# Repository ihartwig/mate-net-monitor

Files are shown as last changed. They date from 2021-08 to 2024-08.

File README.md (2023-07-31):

# mate-net-monitor
Baseboard PCBA for MATE Net and Magnum Net power system monitoring with a Particle Boron.

## GPIO Pin Usage

| Pin | Function | Usage |
|-----|---|---|
| 0 | SDA | -- (expansion connector)
| 1 | SCL | -- (expansion connector)
| 2 | D2 / SPI_SCK | -- (Mag Net activity indicator low)
| 3 | D3 / SPI_MOSI | -- (Mag Net xcvr enable low unpopulated)
| 4 | D4 / SPI_MISO | -- (Mag Net UART TX?)
| 5 | D5 | -- (Mag Net UART RX?)
| 6 | D6 | IRQ from MAX3100 adpt
| 7 | D7 | --
| 8 | D8 | --
| 9 | D9 / UART1_TX | UART from MAX3100 adpt
| 10  | D10 / UART1_RX  | UART to MAX3100 adpt
| 11  | MI | SPI to MAX3100 adpt
| 12  | MO | SPI to MAX3100 adpt
| 13  | SCK | SPI to MAX3100 adpt
| 14  | A5 / SPI_SS | SPI to MAX3100 adpt
| 15  | A4 | -- (expansion connector)
| 16  | A3 | -- (expansion connector)
| 17  | A2 | -- (expansion connector)
| 18  | A1 | -- (expansion connector)
| 19  | A0 | MATE Net activity indicator high
| 20  | | --

## Hardware

* [pcb](pcb) - main baseboard with connectors and interface circuits for MATE Net and Magnum Net
* [pcb-max3100-uart-adpt](pcb-max3100-uart-adpt) - extra max3100 UART port (capable of 9N1) for MATE Net

The `pcb` dc-dc power supply required some rework to achieve stable operation.

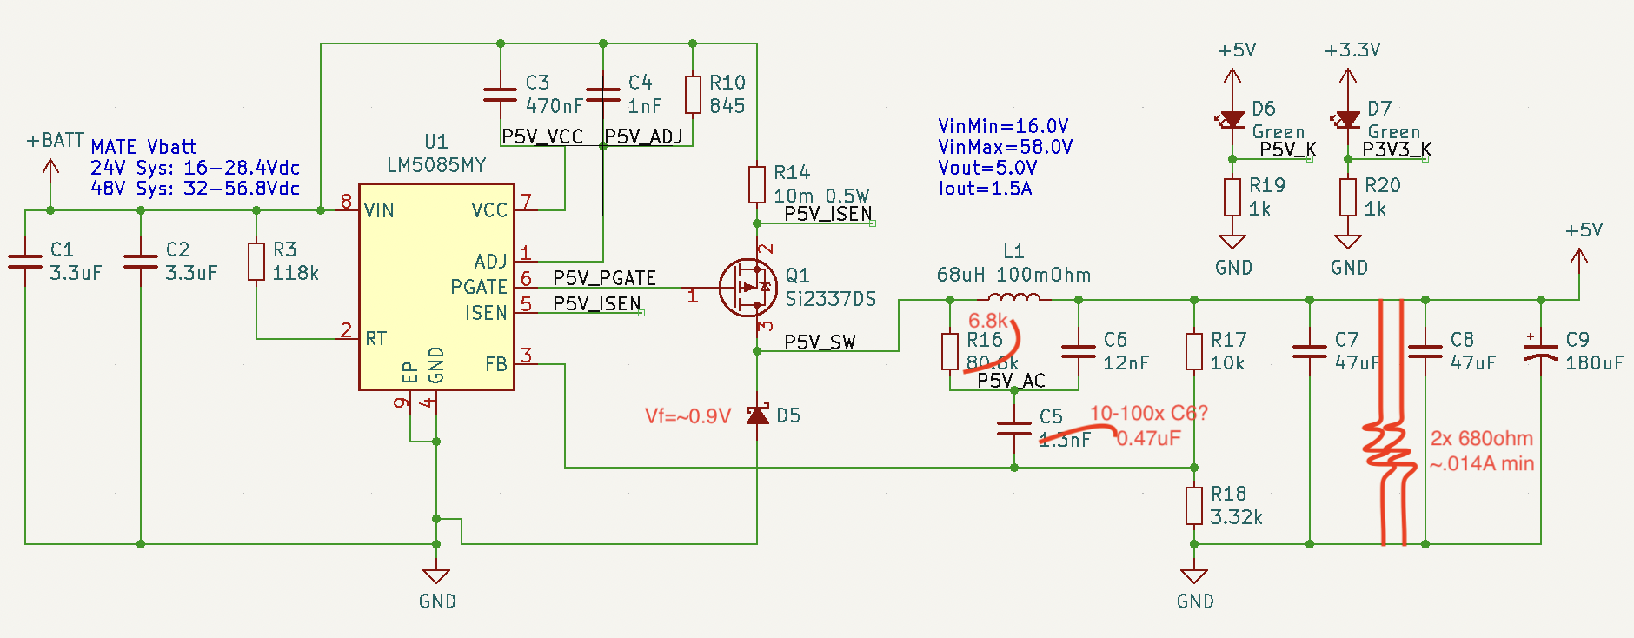
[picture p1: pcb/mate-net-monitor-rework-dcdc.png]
mate-net-monitor-rework-dcdc


Additionally, some modifications during assembly are required compared to the as-designed files here. This primarily addresses pin assignment issues:

* Mag Net is attached to pins that do not have a UART; remap these on the Boron board as the internal UART can be used for this.
* Mate Net needs a 9-bit capable UART; stack the `pcb-max3100-uart-adpt` on the bottom side of the `pcb` mainboard to add this.
  * GND, 3V3, and /IRQ on the far side need to be wired to sources on the mainboard.
  * /SHDN needs to be pulled up (via 10k) to 3V3.

## Firmware

* [fw-mate-net-monitor](fw-mate-net-monitor) - WIP application firmware for reporting MATE inverter stats to particle cloud
* [fw-test](fw-test) - simple hardware test firmware for burn-in testing of interfaces

Inside the `fw-test` folder there is a MAX3100Serial9B library extended from [ewpa's MAX3100Serial](https://github.com/ewpa/MAX3100Serial) with some adaptations to Particle and significant new features:

* addition of software buffers and interrupt handling for continuous stream operation
* irq, sent, read, and overflow counters
* (WIP) 9-bit read and write configuration

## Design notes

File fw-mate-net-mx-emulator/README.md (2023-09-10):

# fw-mate-net-monitor

A Particle project named fw-mate-net-monitor

This project implements the uMATE library on top of Particle Boron with a mate-net-monitor adapter board to act like the status screen on a MATE controller and save this data to a cloud database.

More details on the [MATE-to-MX protocol](https://github.com/jorticus/pymate/blob/master/doc/protocol/Protocol.md) have been documented by jorticus - thank you! The simple implementation here requests the device type and status page from port 0 every 3 minutes. The bus is scanned more frequently (approx. every 1 second) to drive MATE Net LEDs.

#### LED Indicators:

MATE Net Port Green: powered up (+24V) from this port

MATE Net Port Orange: solid for running port scan; blinking when at least one MATE device is found during last scan

Mag Net Green: ports A and B are connected correctly based on the +14V power; power is not drawn from this port

Mag Net Orange: not implemented

Mag Net Red: ports A and B are swapped

#### Limitations:
* always asks for the MX Charger status on port 0 if it is not discovered on another port
* * mate bus scan to discover devices behind Hub is implemented, but not tested with a Hub
* Mag net ports are not implemented - should have no impact since that is a multi-drop bus

#### Topology:

```
Particle Cloud
       |
      LTE
       |               MAX3100 UART &
     Boron --- SPI --- Opto-Isolation --- MATE-net --- MX Charger
                       3.3V       24V
```

#### Library modifications:

* uMate has extra #define OUT statements commented for conflict with Particle libs
* MAX3100Serial9b includes a compatible Stream9b.h to the one used in uMate

## Welcome to your project!

Every new Particle project is composed of 3 important elements that you'll see have been created in your project directory for fw-mate-net-monitor.

#### ```/src``` folder:  
This is the source folder that contains the firmware files for your project. It should *not* be renamed. 
Anything that is in this folder when you compile your project will be sent to our compile service and compiled into a firmware binary for the Particle device that you have targeted.

If your application contains multiple files, they should all be included in the `src` folder. If your firmware depends on Particle libraries, those dependencies are specified in the `project.properties` file referenced below.

#### ```.ino``` file:
This file is the firmware that will run as the primary application on your Particle device. It contains a `setup()` and `loop()` function, and can be written in Wiring or C/C++. For more information about using the Particle firmware API to create firmware for your Particle device, refer to the [Firmware Reference](https://docs.particle.io/reference/firmware/) section of the Particle documentation.

#### ```project.properties``` file:  
This is the file that specifies the name and version number of the libraries that your project depends on. Dependencies are added automatically to your `project.properties` file when you add a library to a project using the `particle library add` command in the CLI or add a library in the Desktop IDE.

## Adding additional files to your project

#### Projects with multiple sources
If you would like add additional files to your application, they should be added to the `/src` folder. All files in the `/src` folder will be sent to the Particle Cloud to produce a compiled binary.

#### Projects with external libraries
If your project includes a library that has not been registered in the Particle libraries system, you should create a new folder named `/lib/<libraryname>/src` under `/<project dir>` and add the `.h`, `.cpp` & `library.properties` files for your library there. Read the [Firmware Libraries guide](https://docs.particle.io/guide/tools-and-features/libraries/) for more details on how to develop libraries. Note that all contents of the `/lib` folder and subfolders will also be sent to the Cloud for compilation.

## Compiling your project

When you're ready to compile your project, make sure you have the correct Particle device target selected and run `particle compile <platform>` in the CLI or click the Compile button in the Desktop IDE. The following files in your project folder will be sent to the compile service:

- Everything in the `/src` folder, including your `.ino` application file
- The `project.properties` file for your project
- Any libraries stored under `lib/<libraryname>/src`

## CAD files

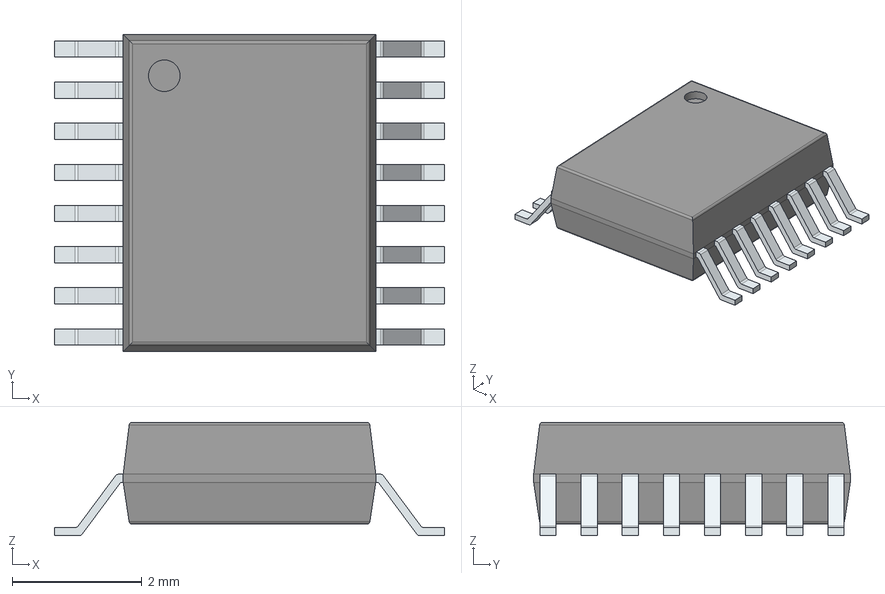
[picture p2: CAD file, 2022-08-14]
pcb-max3100-uart-adpt/max3100-uart-adpt-special-packages3d/MAX3100EEE+.stp
6.02 x 4.89 x 1.75 mm
PinsArrayLR

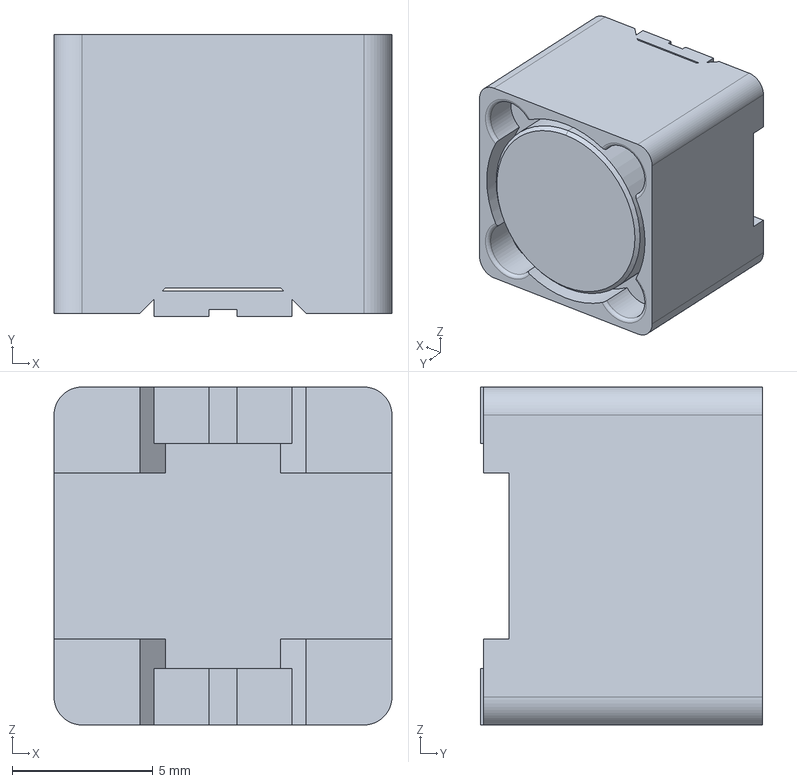
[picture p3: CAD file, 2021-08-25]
pcb/mate-net-monitor-special-packages3d/L_Bourns_SRR1210.stp
12.0 x 10.0 x 12.0 mm

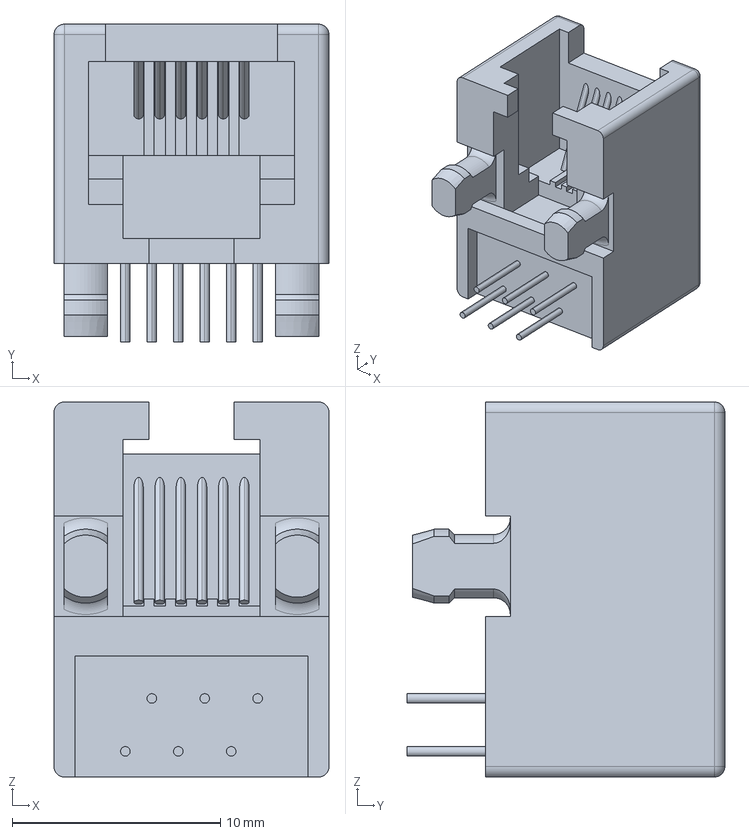
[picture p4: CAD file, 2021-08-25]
pcb/mate-net-monitor-special-packages3d/RJ12_Amphenol_54601.stp
13.2 x 15.2 x 18.0 mm

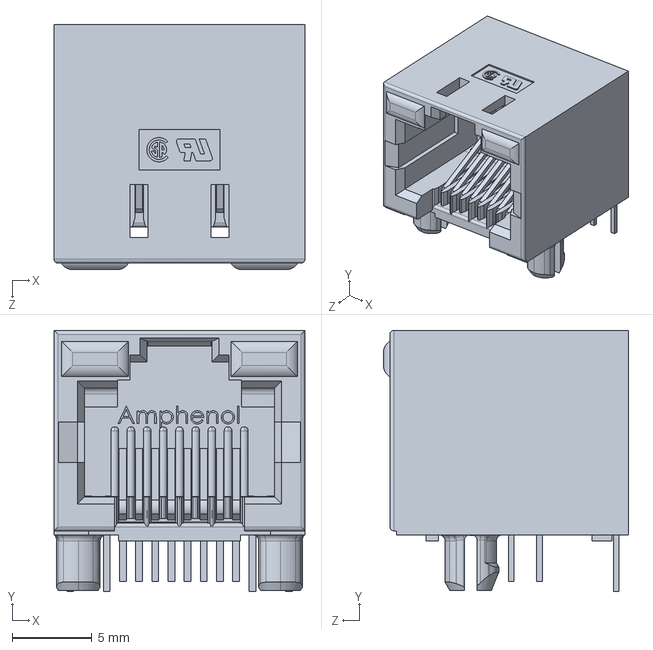
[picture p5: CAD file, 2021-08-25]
pcb/mate-net-monitor-special-packages3d/RJ45_Amphenol_RJHSE508X.step
15.7 x 16.4 x 15.4 mm

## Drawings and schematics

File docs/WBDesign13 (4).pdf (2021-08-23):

## WEBENCH ® Design Report

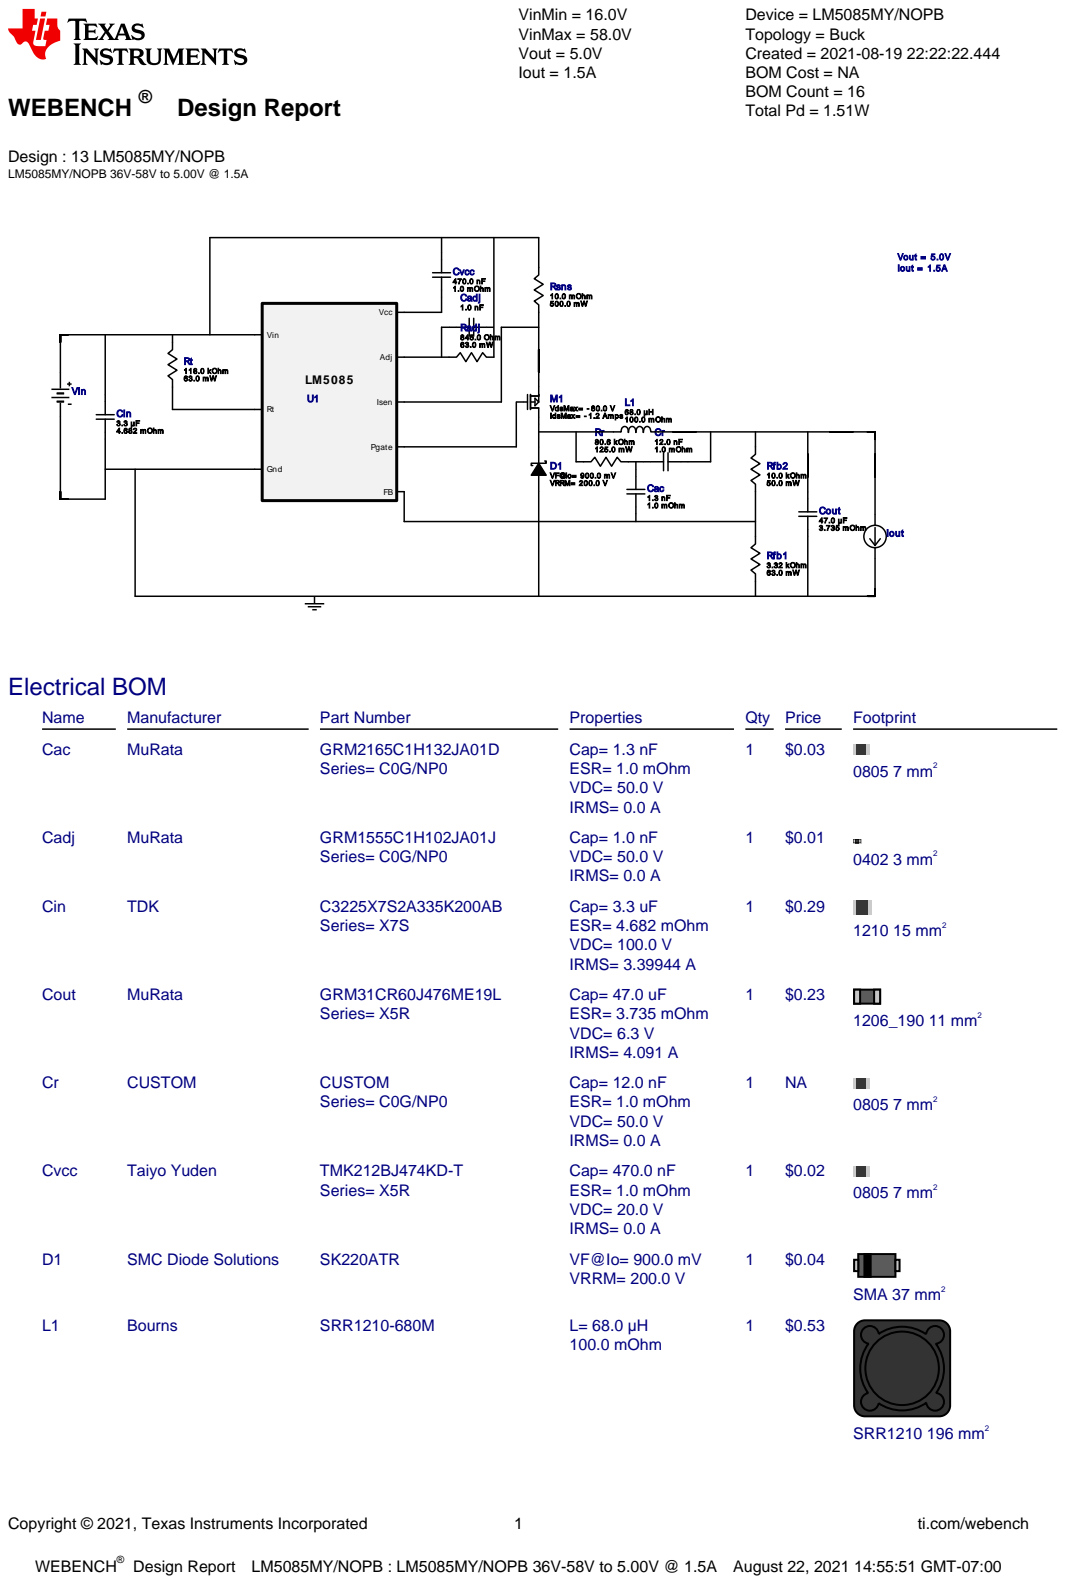
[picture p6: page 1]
Copyright © 2021, Texas Instruments Incorporated; ti.com/webench; WEBENCH®; Design : 13 LM5085MY/NOPB LM5085MY/NOPB 36V-58V to 5.00V @ 1.5A; VinMin = 16.0V VinMax = 58.0V Vout = 5.0V Iout = 1.5A; Cac 1.3 nF 1.0 mOhm; Cadj 1.0 nF; Cin 3.3 µF 4.682 mOhm; Cout 47.0 µF 3.735 mOhm; Cr 12.0 nF 1.0 mOhm; Cvcc 470.0 nF 1.0 mOhm; D1 VF@Io= 900.0 mV VRRM= 200.0 V; L1 68.0 µH 100.0 mOhm; M1 VdsMax= - 80.0 V IdsMax= - 1.2 Amps; Radj 845.0 Ohm 63.0 mW; Rfb1 3.32 kOhm 63.0 mW; Rfb2 10.0 kOhm 50.0 mW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

Device = LM5085MY/NOPB
Topology = Buck
Created = 2021-08-19 22:22:22.444
BOM Cost = NA
BOM Count = 16
Total Pd = 1.51W

Design Report LM5085MY/NOPB : LM5085MY/NOPB 36V-58V to 5.00V @ 1.5A August 22, 2021 14:55:51 GMT-07:00

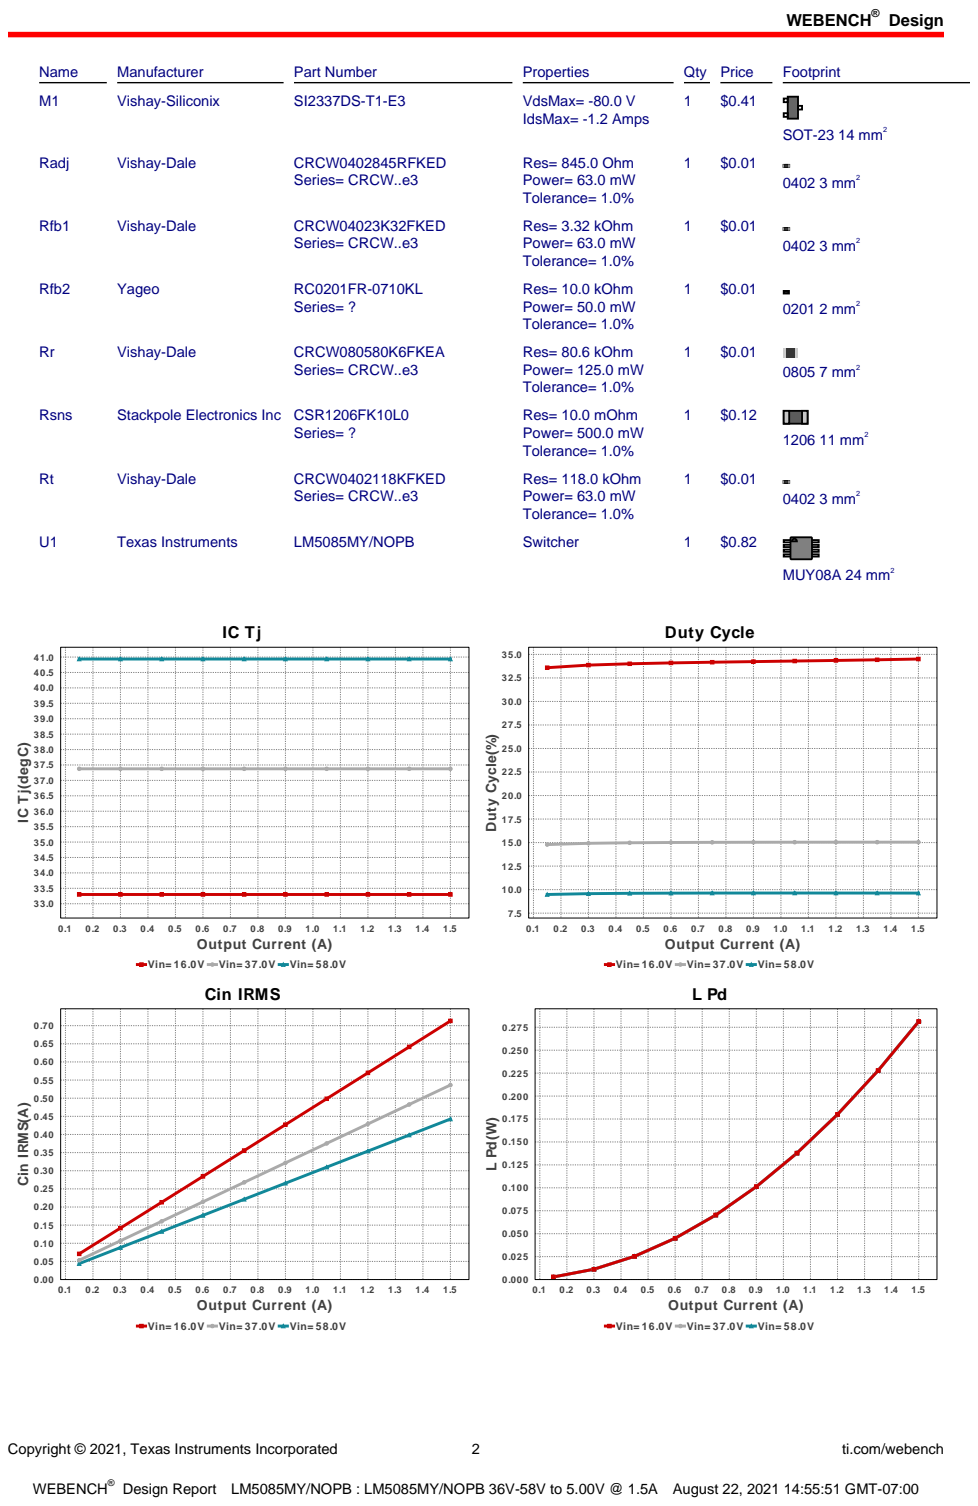
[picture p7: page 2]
Design; Copyright © 2021, Texas Instruments Incorporated; ti.com/webench; Name; Manufacturer; Part Number; Properties; Qty Price; Footprint; Vishay-Siliconix; VdsMax= -80.0 V; IdsMax= -1.2 Amps; SOT-23 14 mm²; Radj; Vishay-Dale; CRCW0402845RFKED; Series= CRCW..e3; Res= 845.0 Ohm Power= 63.0 mW Tolerance= 1.0%; 0402 3 mm²; Rfb1; CRCW04023K32FKED; Res= 3.32 kOhm Power= 63.0 mW Tolerance= 1.0%; Rfb2; Yageo; Series= ?; Res= 10.0 kOhm Power= 50.0 mW Tolerance= 1.0%; 0201 2 mm²; CRCW080580K6FKEA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

IC Tj(degC)

Vin= 16.0V Vin= 37.0V Vin= 58.0V
Cin IRMS

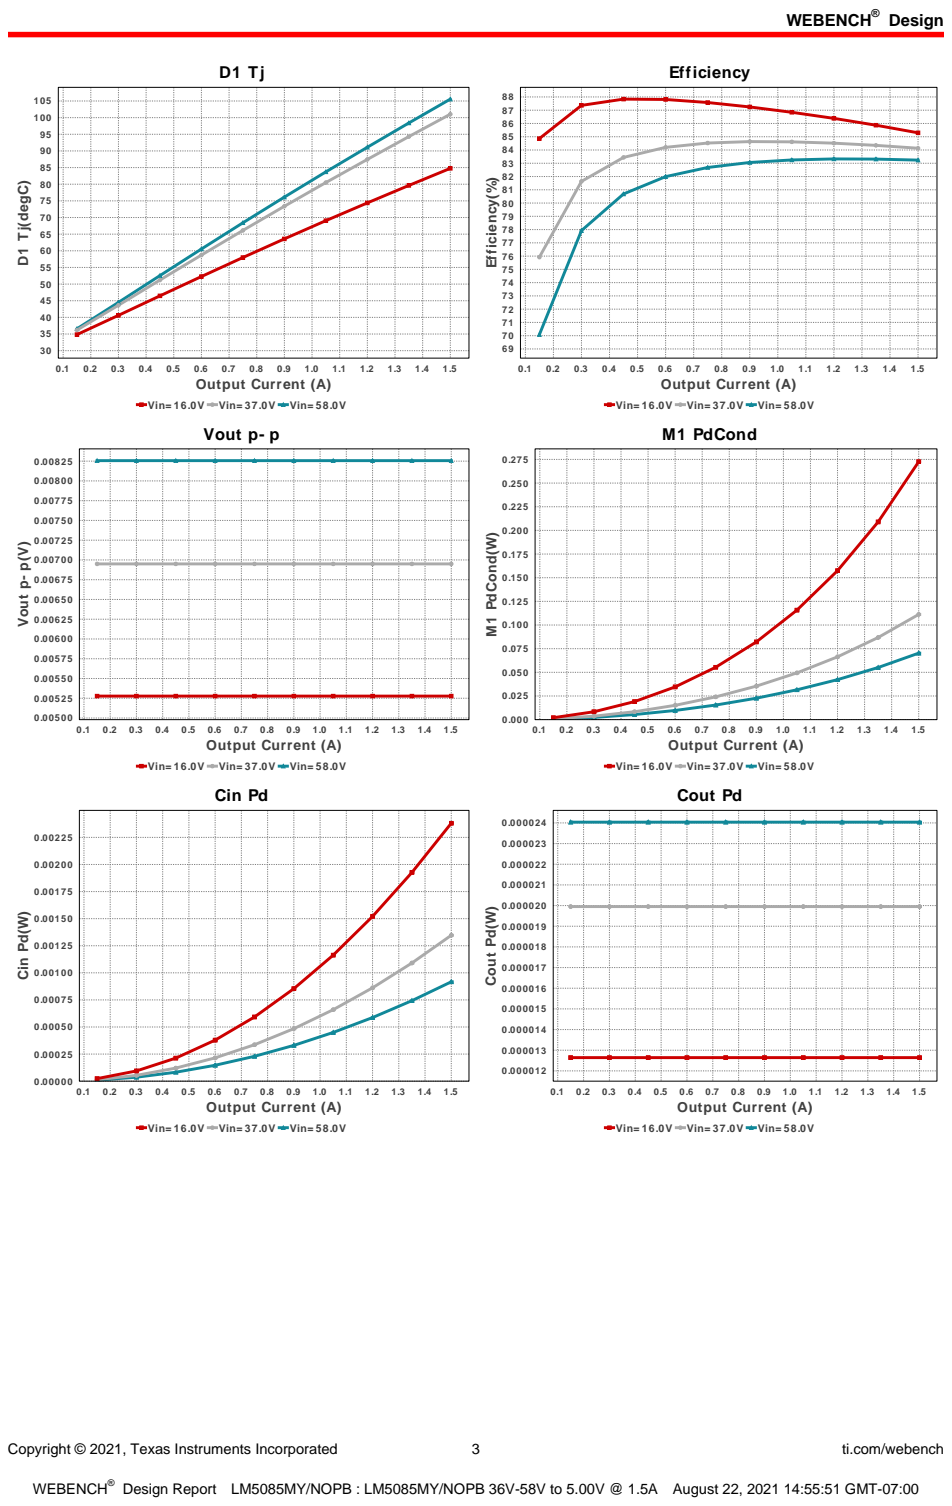
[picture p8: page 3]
Copyright © 2021, Texas Instruments Incorporated; ti.com/webench; 1.5 Output Current (A); D1 Tj(degC); Efficiency; Efficiency(%); 0.1 0.2 0.3 0.4 0.5 0.6 0.7 0.8 0.9 1.0 1.1 1.2 1.3 1.4 1.5 Output Current (A); Vout p- p(V); M1 PdCond(W); Cin Pd; Cin Pd(W); Cout Pd; Cout Pd(W)

Vin= 16.0V Vin= 37.0V Vin= 58.0V
Vout p- p

M1 PdCond

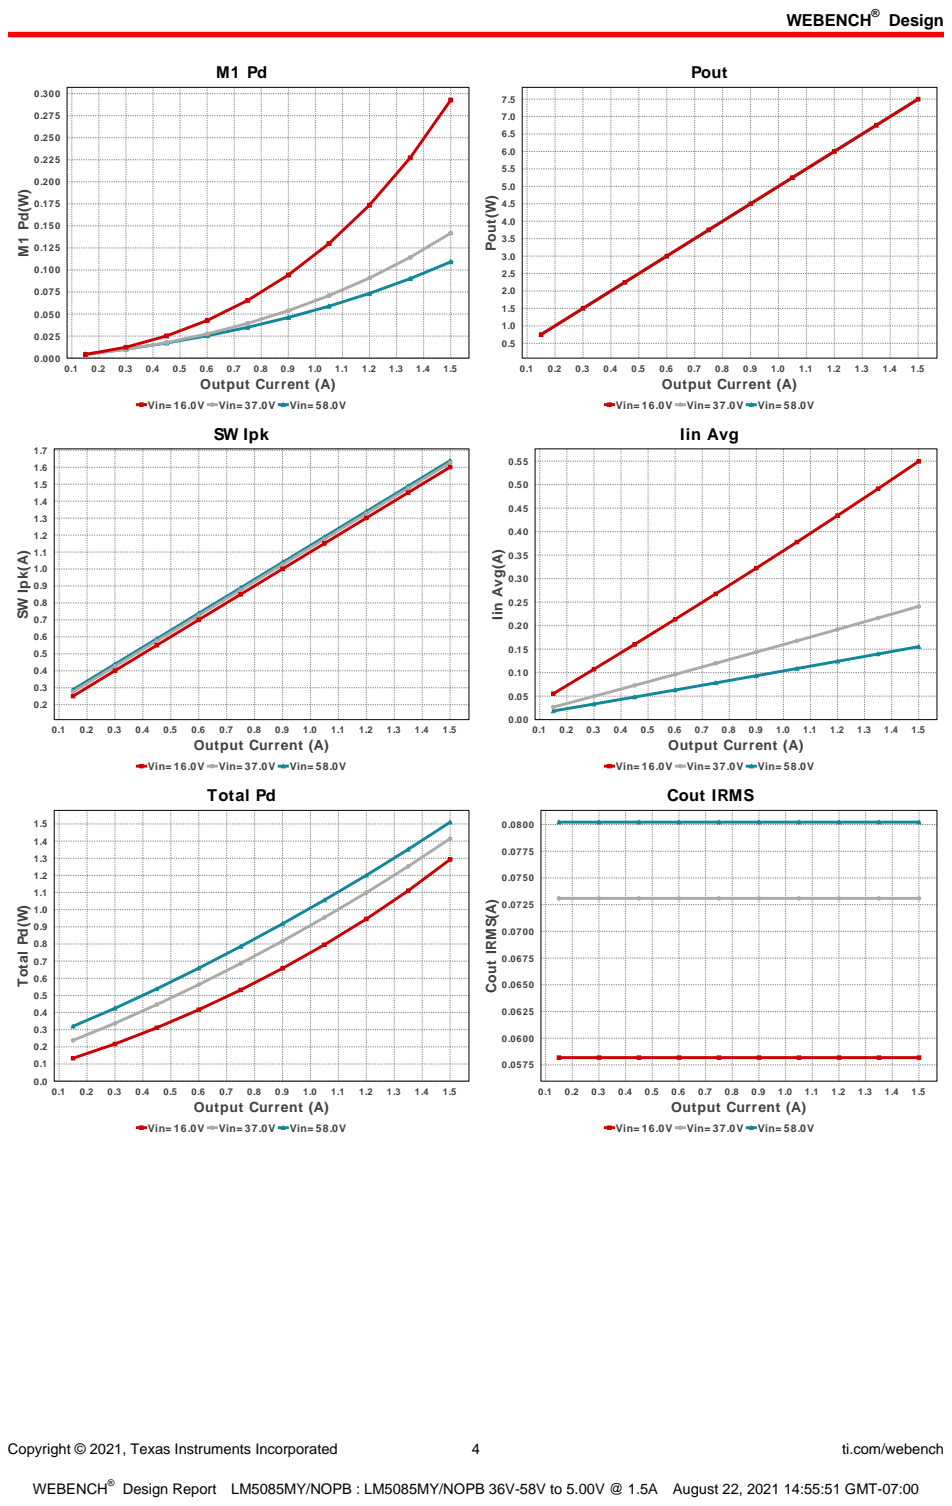
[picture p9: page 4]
Copyright © 2021, Texas Instruments Incorporated; ti.com/webench; 1.5 Output Current (A); Pout; Pout(W); SW Ipk; SW Ipk(A); Iin Avg; Iin Avg(A); Total Pd; Total Pd(W); 0.1 0.2 0.3 0.4 0.5 0.6 0.7 0.8 0.9 1.0 1.1 1.2 1.3 1.4 1.5 Output Current (A); Cout IRMS(A)

Vin= 16.0V Vin= 37.0V Vin= 58.0V

Cout IRMS

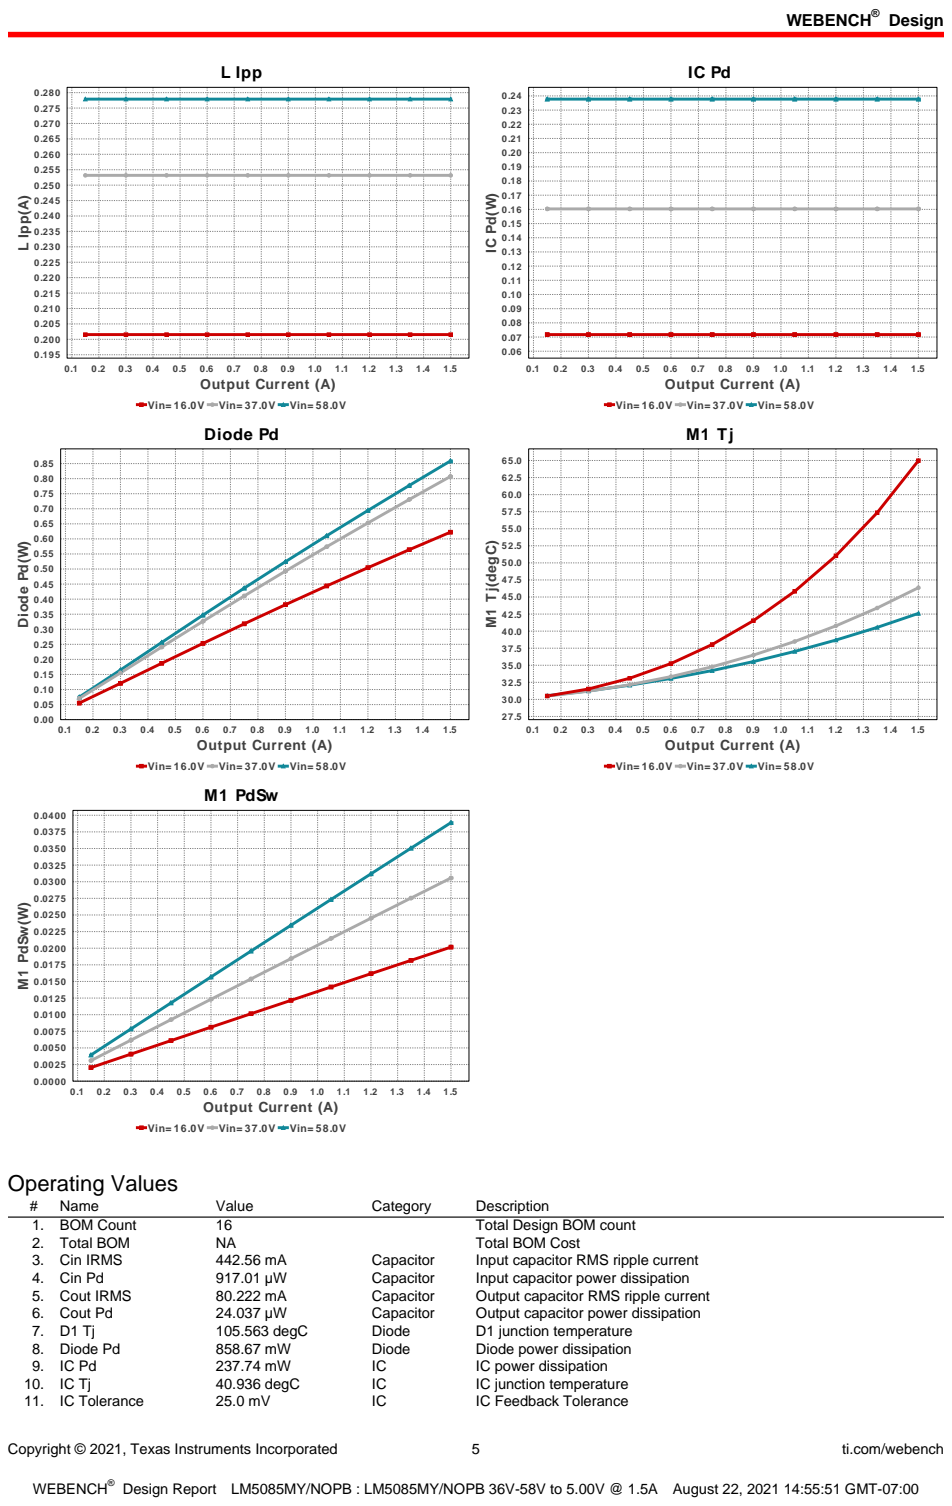
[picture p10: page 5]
Copyright © 2021, Texas Instruments Incorporated; ti.com/webench; L Ipp; 1.5 Output Current (A); L Ipp(A); Diode Pd(W); M1 Tj(degC); 0.1 0.2 0.3 0.4 0.5 0.6 0.7 0.8 0.9 1.0 1.1 1.2 1.3 1.4 1.5 Output Current (A); M1 PdSw(W); Operating Values; Name; Value; Category; Description; 1. BOM Count; Total Design BOM count; 2. Total BOM; Total BOM Cost; 3. Cin IRMS; Capacitor; Input capacitor RMS ripple current; 4. Cin Pd; Input capacitor power dissipation; 5. Cout IRMS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

Vin= 16.0V Vin= 37.0V Vin= 58.0V
Diode Pd

M1 PdSw

Copyright © 2021, Texas Instruments Incorporated | 6 | ti.com/webench
# | Name | Value | Category | Description

12. ICThetaJA | 46.0 degC/W | IC | IC junction-to-ambient thermal resistance
13. Iin Avg | 155.35 mA | IC | Average input current
14. L Ipp | 277.898 mA | Inductor | Peak-to-peak inductor ripple current
15. L Pd | 281.25 mW | Inductor | Inductor power dissipation
16. M1 Pd | 109.18 mW | Mosfet | M1 MOSFET total power dissipation
17. M1 PdCond | 70.287 mW | Mosfet | M1 MOSFET conduction losses
18. M1 PdSw | 38.892 mW | Mosfet | M1 MOSFET switching losses
19. M1 Tj | 42.599 degC | Mosfet | M1 MOSFET junction temperature
20. Cin Pd | 917.01 µW | Power | Input capacitor power dissipation
21. Cout Pd | 24.037 µW | Power | Output capacitor power dissipation
22. Diode Pd | 858.67 mW | Power | Diode power dissipation
23. IC Pd | 237.74 mW | Power | IC power dissipation
24. L Pd | 281.25 mW | Power | Inductor power dissipation
25. M1 Pd | 109.18 mW | Power | M1 MOSFET total power dissipation
26. M1 PdCond | 70.287 mW | Power | M1 MOSFET conduction losses
27. M1 PdSw | 38.892 mW | Power | M1 MOSFET switching losses
28. Total Pd | 1.51 W | Power | Total Power Dissipation
29. Duty Cycle | 9.633 % | System
| | | Information | Duty cycle
30. Efficiency | 83.238 % | System
| | | Information | Steady state efficiency
31. FootPrint | 349.0 mm² | System
| | | Information | Total Foot Print Area of BOM components
32. Frequency | 212.046 kHz | System
| | | Information | Switching frequency
33. Iout | 1.5 A | System
| | | Information | Iout operating point
34. Mode | CCM | System
| | | Information | Conduction Mode
35. Pout | 7.5 W | System
| | | Information | Total output power
36. SW Ipk | 1.639 A | System
| | | Information | Peak switch current
37. Vin | 58.0 V | System
| | | Information | Vin operating point
38. Vout | 5.0 V | System
| | | Information | Operational Output Voltage
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

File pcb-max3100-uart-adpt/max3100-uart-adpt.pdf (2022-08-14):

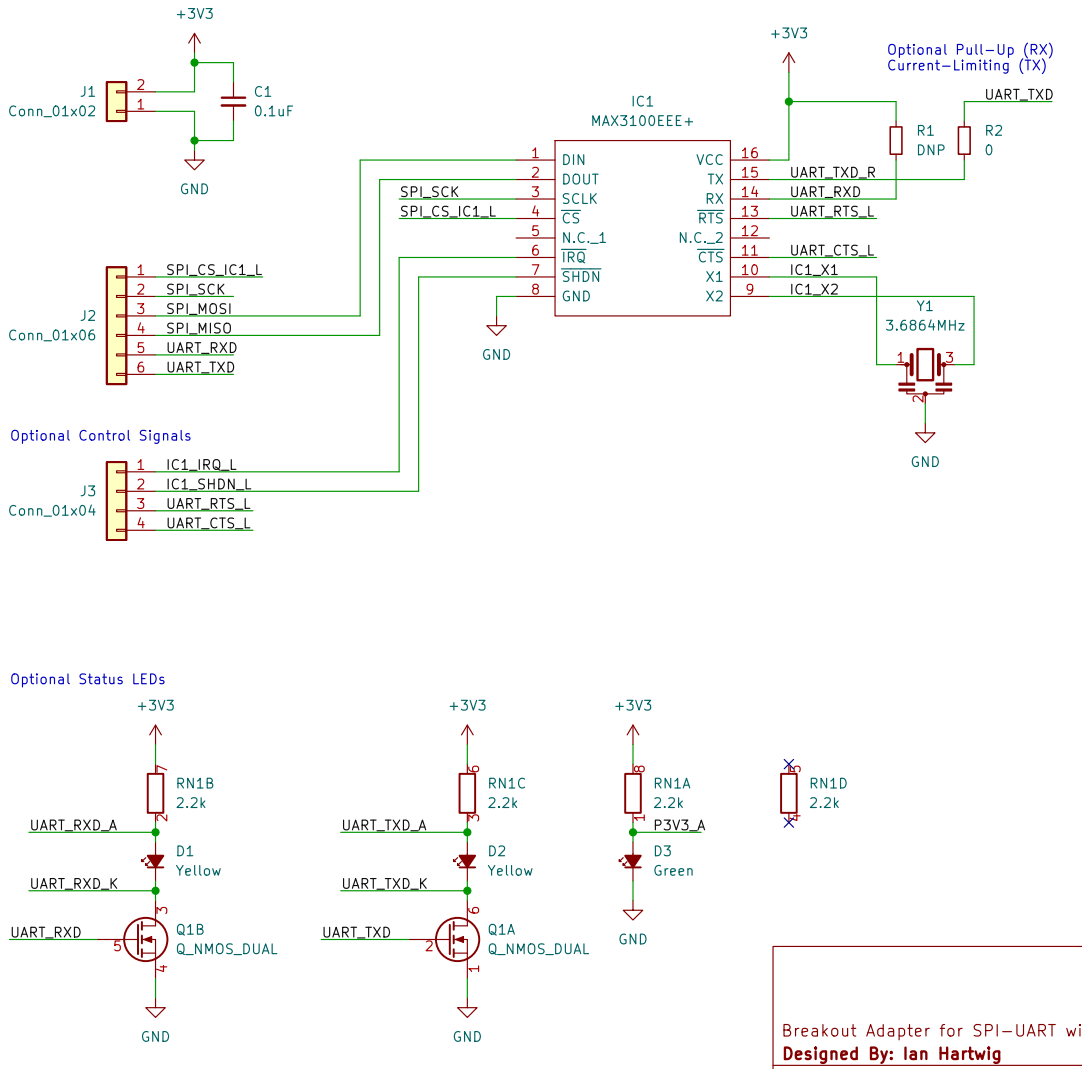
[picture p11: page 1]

Optional Pull-Up (RX)
Current-Limiting (TX)

3.6864MHz GND GND
Breakout Adapter for SPI-UART with pin layout matching mate-net-monitor baseboard GND

File: max3100-uart-adpt.kicad_sch Sheet: / Designed By: Ian Hartwig

Id: 1/1 Title: MAX3100 UART Adapter

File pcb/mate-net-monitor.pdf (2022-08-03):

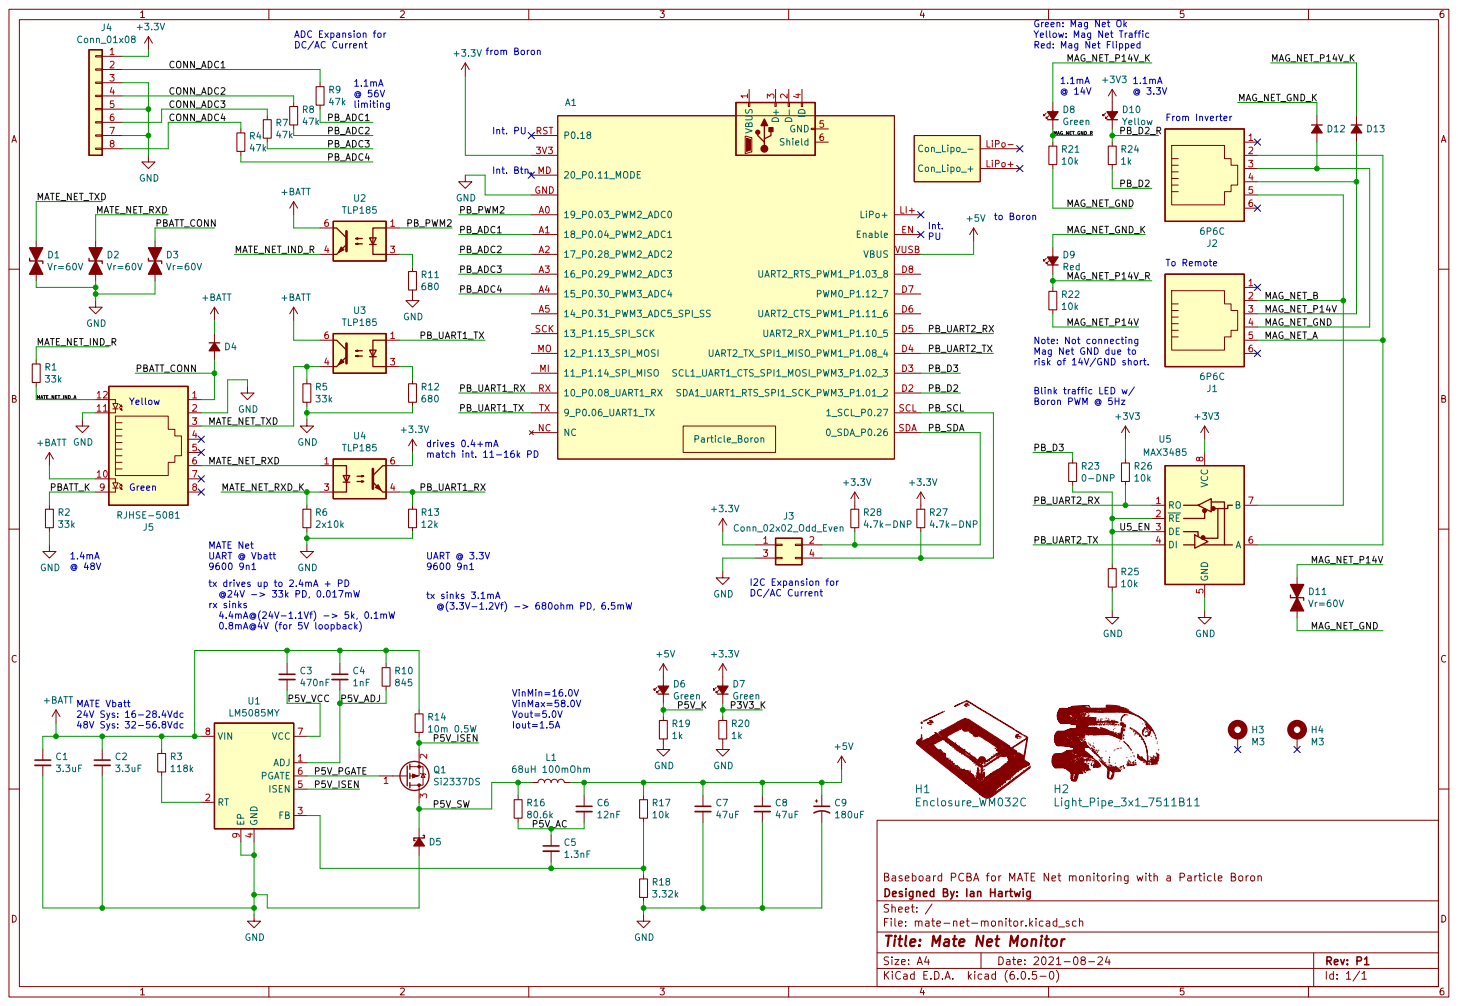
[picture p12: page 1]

1.1mA @ 14V Green: Mag Net Ok
Yellow: Mag Net Traffic
Red: Mag Net Flipped
From Inverter To Remote

risk of 14V/GND short. 1.4mA @ 48V MATE Vbatt 24V Sys: 16-28.4Vdc

Mag Net GND due to

drives 0.4+mA match int. 11-16k PD

tx drives up to 2.4mA + PD
rx sinks
0.8mA@4V (for 5V loopback)

I2C Expansion for DC/AC Current

Baseboard PCBA for MATE Net monitoring with a Particle Boron
File: mate-net-monitor.kicad_sch Sheet: / Designed By: Ian Hartwig

Id: 1/1 Title: Mate Net Monitor

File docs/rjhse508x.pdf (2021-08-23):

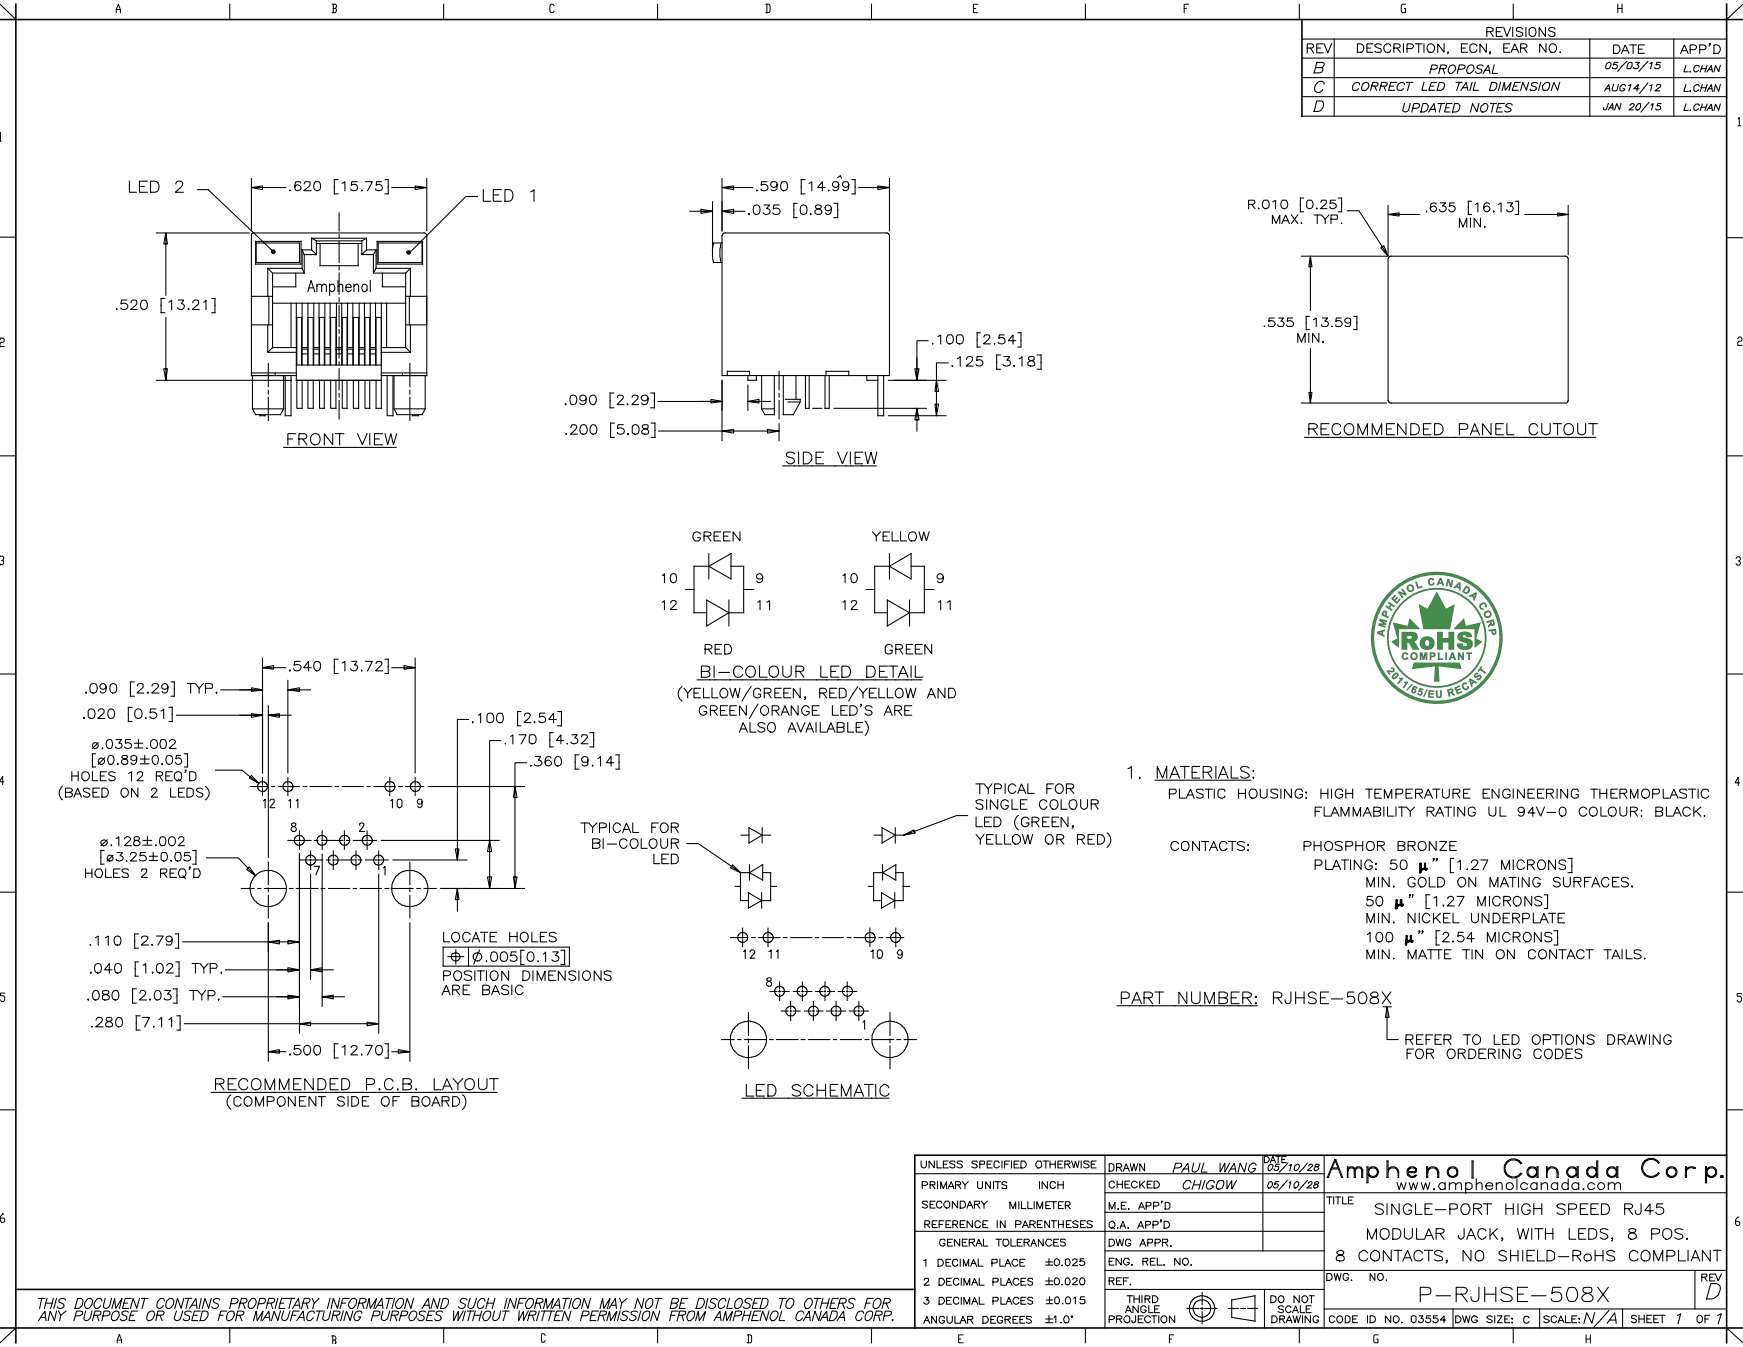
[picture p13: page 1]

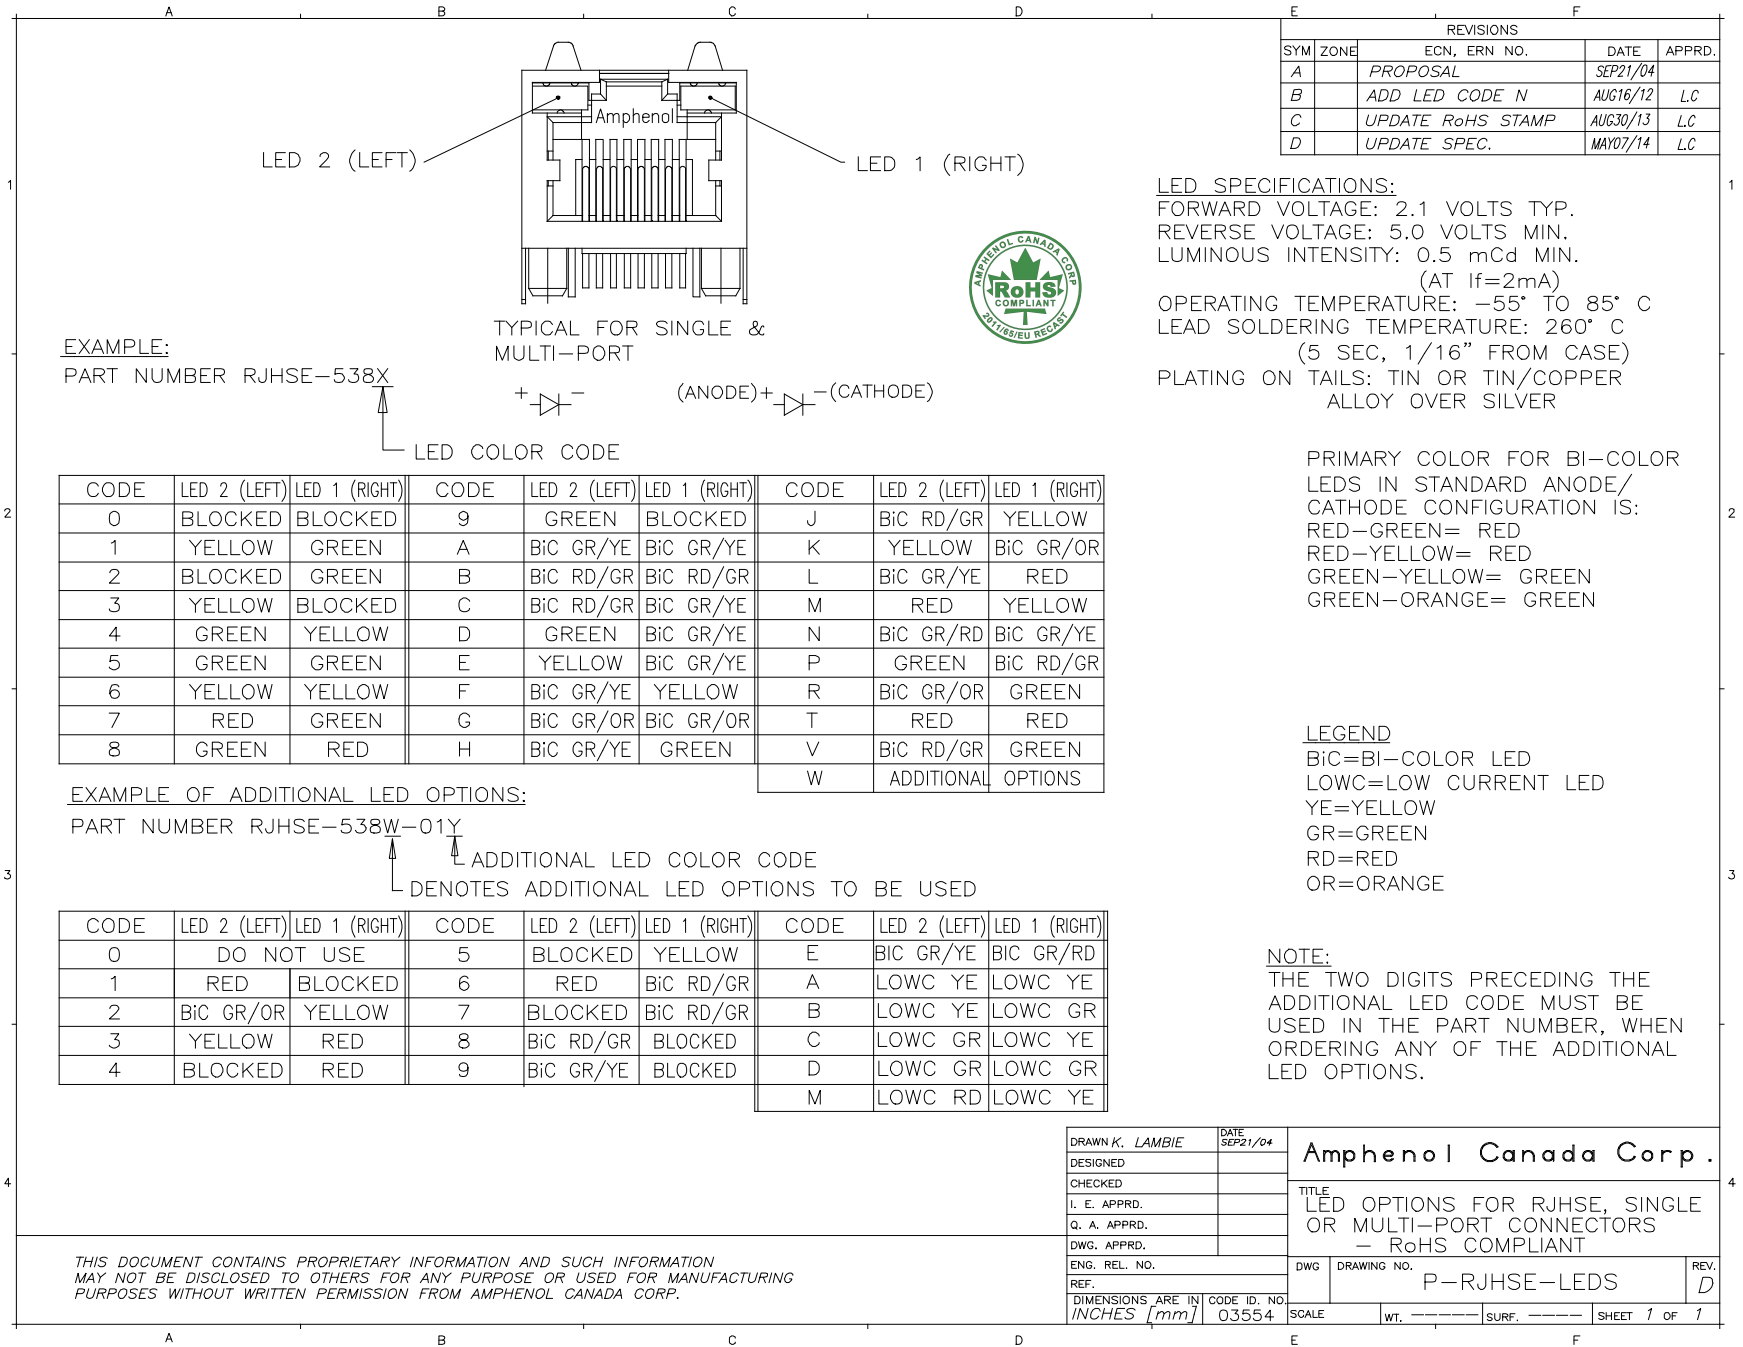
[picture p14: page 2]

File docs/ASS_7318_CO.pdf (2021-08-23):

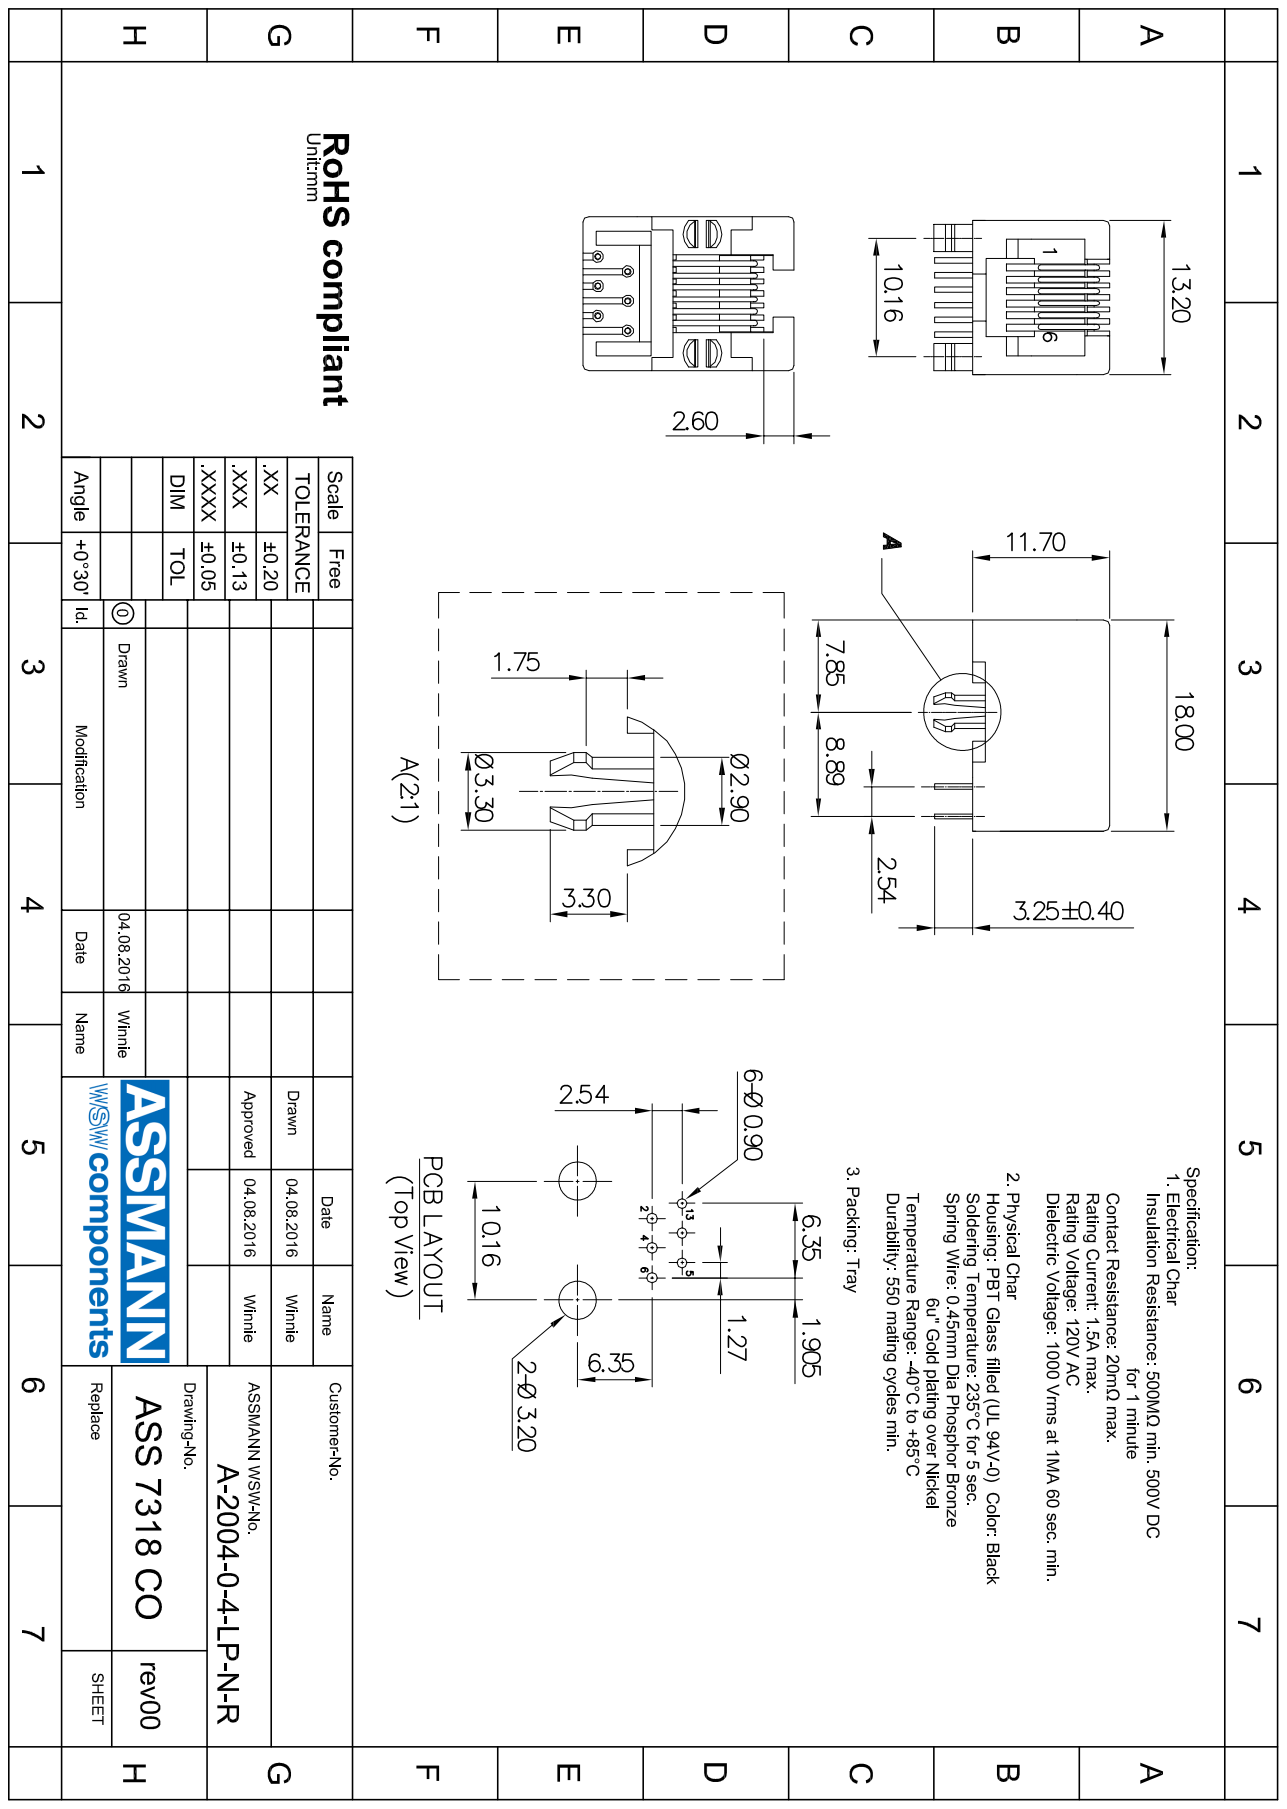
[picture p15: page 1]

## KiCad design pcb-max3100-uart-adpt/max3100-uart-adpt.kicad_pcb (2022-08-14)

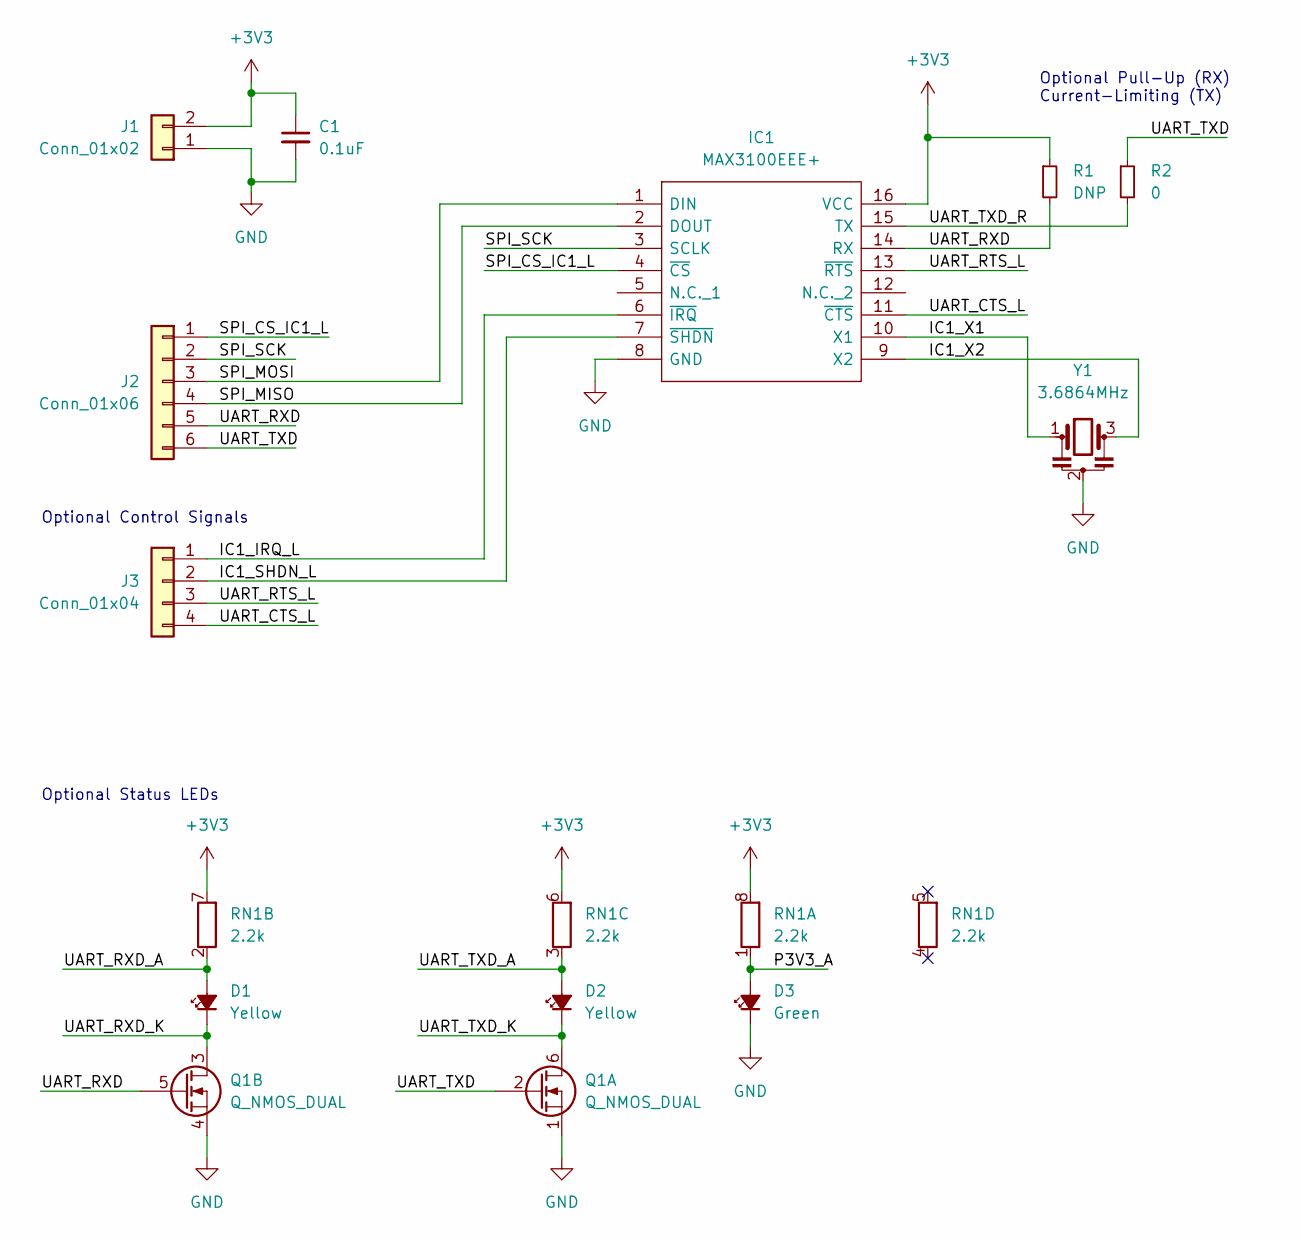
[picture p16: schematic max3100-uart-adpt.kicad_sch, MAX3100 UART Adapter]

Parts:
C1: 0.1uF; C_0805_2012Metric
D1, D2: Yellow; LED_0603_1608Metric
D3: Green; LED_0603_1608Metric
IC1: MAX3100EEE+; SOP64P602X175-16N; Manufacturer_Part_Number MAX3100EEE+; Mouser Part Number 700-MAX3100EEE
J1: Conn_01x02; PinHeader_1x02_P2.54mm_Vertical
J2: Conn_01x06; PinHeader_1x06_P2.54mm_Vertical
J3: Conn_01x04; PinHeader_1x04_P2.54mm_Vertical
Q1: Q_NMOS_DUAL; SOT-23-6; Mfg PN DMN5L06DMK-7
R1: DNP; R_0805_2012Metric
R2: 0; R_0805_2012Metric
RN1: 2.2k; R_Array_Convex_4x0603; Mfg PN YC164-JR-072K2L
Y1: 3.6864MHz; AWSCR368CPLAC30T4; Mfg PN AWSCR-3.68CPLA-C30-T4

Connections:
+3V3: C1.1, IC1.16 (VCC), J1.2, R1.1, RN1.6 (R1.2), RN1.7 (R1.2), RN1.8 (R1.2)
/IC1_IRQ_L: IC1.6 (~IRQ), J3.1
/IC1_SHDN_L: IC1.7 (~SHDN), J3.2
/IC1_X1: IC1.10 (X1), Y1.1
/IC1_X2: IC1.9 (X2), Y1.3
/P3V3_A: D3.2 (A), RN1.1 (R1.1)
/SPI_CS_IC1_L: IC1.4 (~CS), J2.1
/SPI_MISO: IC1.2 (DOUT), J2.4
/SPI_MOSI: IC1.1 (DIN), J2.3
/SPI_SCK: IC1.3 (SCLK), J2.2
/UART_CTS_L: IC1.11 (~CTS), J3.4
/UART_RTS_L: IC1.13 (~RTS), J3.3
/UART_RXD: IC1.14 (RX), J2.5, Q1.5 (G), R1.2
/UART_RXD_A: D1.2 (A), RN1.2 (R1.1)
/UART_RXD_K: D1.1 (K), Q1.3 (D)
/UART_TXD: J2.6, Q1.2 (G), R2.1
/UART_TXD_A: D2.2 (A), RN1.3 (R1.1)
/UART_TXD_K: D2.1 (K), Q1.6 (D)
/UART_TXD_R: IC1.15 (TX), R2.2
GND: C1.2, D3.1 (K), IC1.8 (GND), J1.1, Q1.1 (S), Q1.4 (S), Y1.2

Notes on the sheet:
Optional Status LEDs
Optional Pull-Up (RX) Current-Limiting (TX)
Optional Control Signals

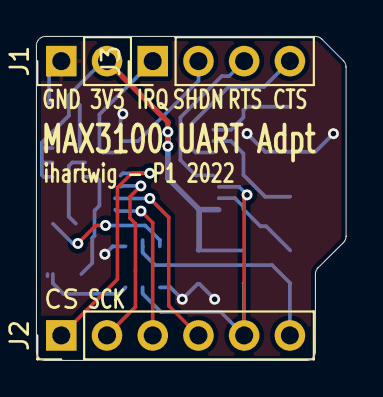
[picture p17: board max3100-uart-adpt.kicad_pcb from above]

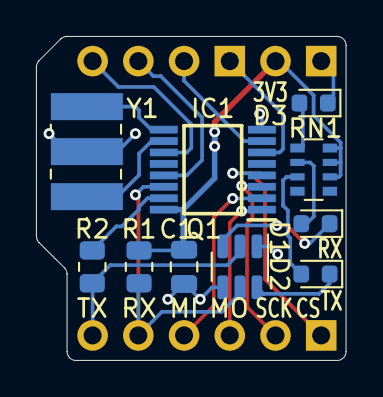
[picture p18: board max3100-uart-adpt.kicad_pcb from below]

Board: 2 copper layers, 17.2 x 18.0 mm, 14 parts (10 on the bottom side), 20 nets.

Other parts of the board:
H1: Enclosure_WM032C

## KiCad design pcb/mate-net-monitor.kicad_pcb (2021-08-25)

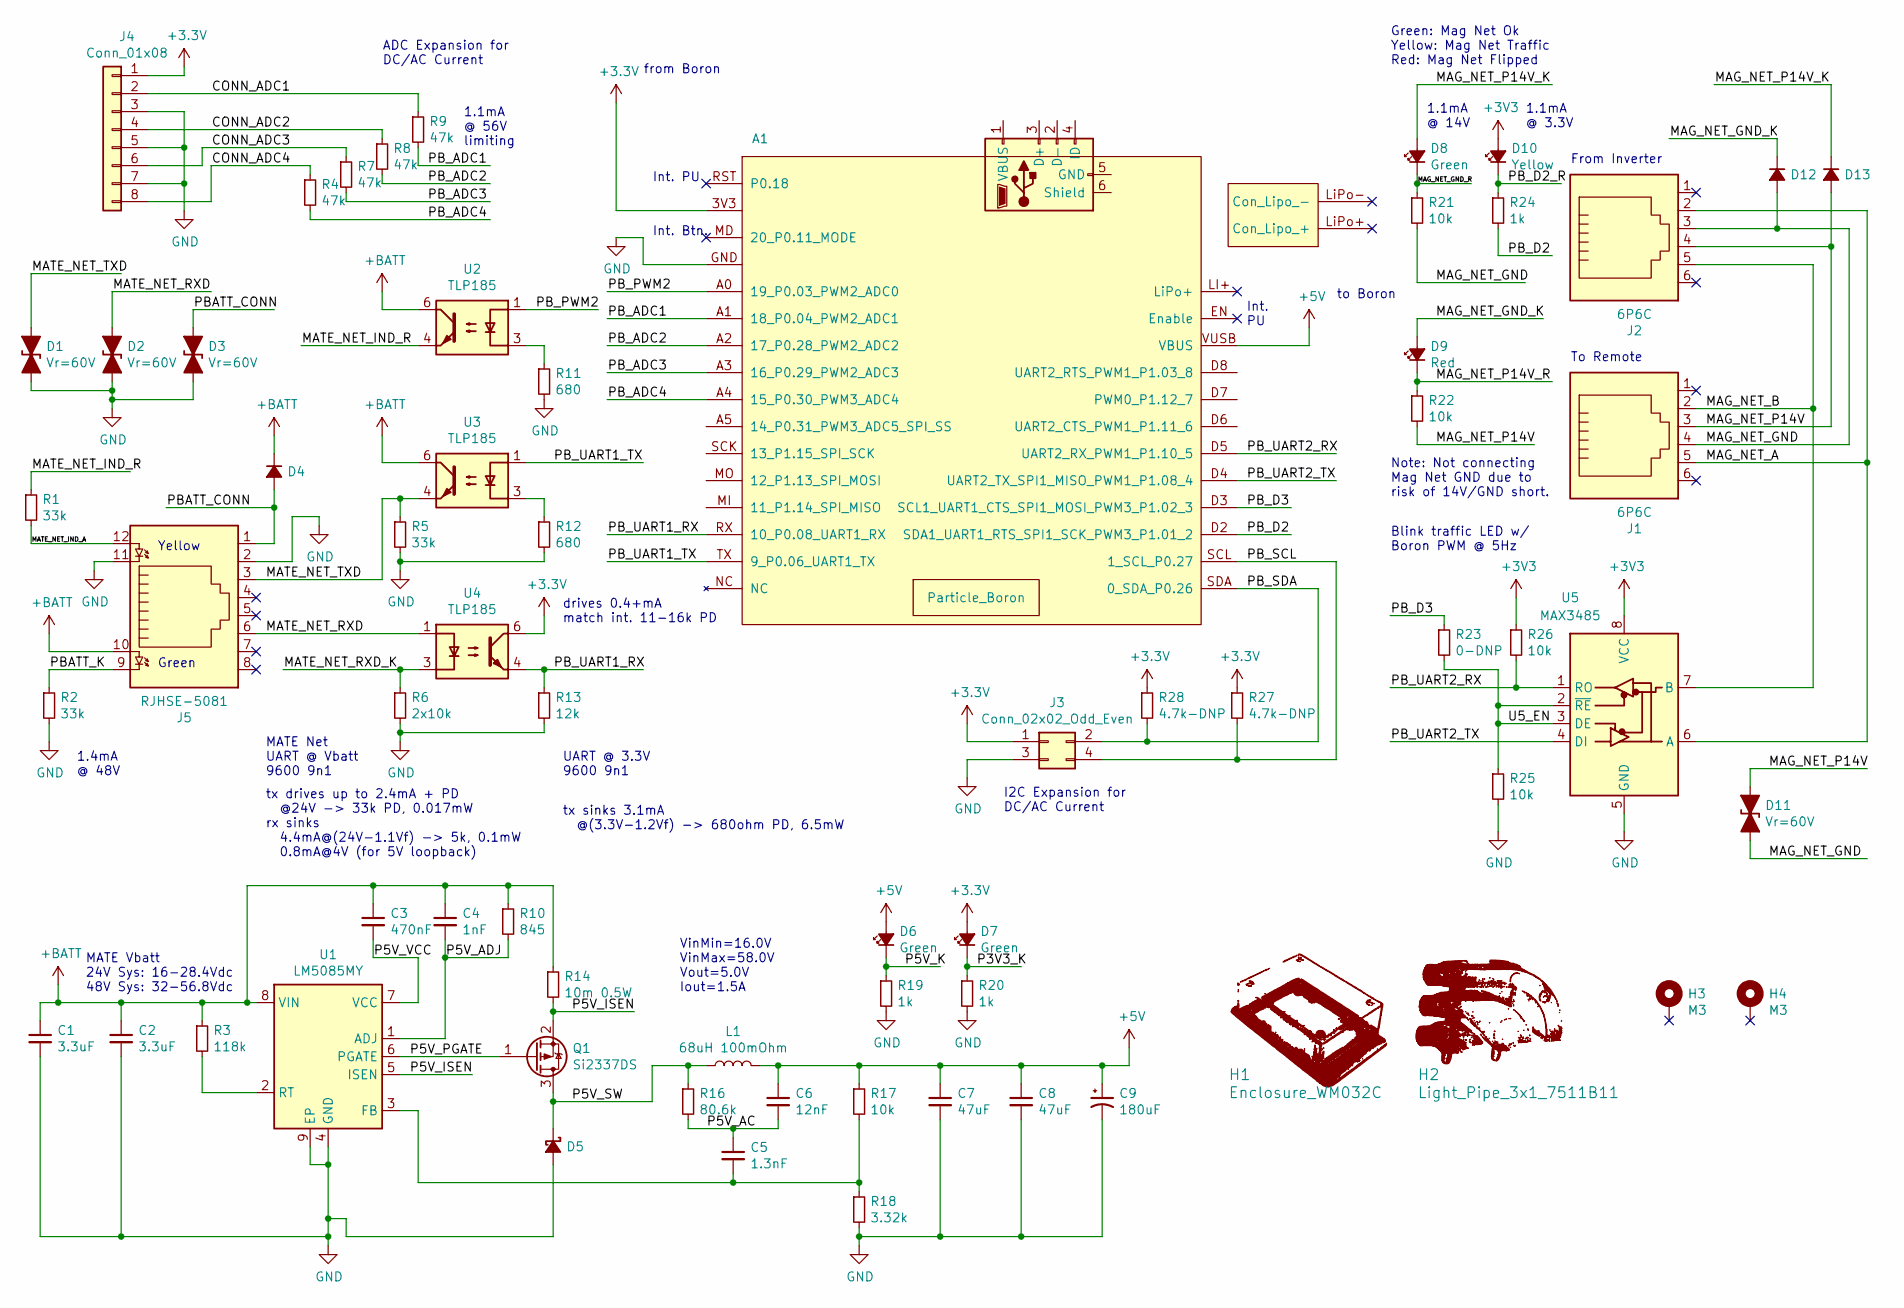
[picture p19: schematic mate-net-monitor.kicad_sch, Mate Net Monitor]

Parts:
A1: Particle_Boron; Particle_Boron_1x16_1x12_P2.54mm
C1, C2: 3.3uF; C_1210_3225Metric
C3: 470nF; C_0805_2012Metric
C4: 1nF; C_0805_2012Metric
C5: 1.3nF; C_0805_2012Metric
C6: 12nF; C_0805_2012Metric
C7, C8: 47uF; C_1206_3216Metric
C9: 180uF; CP_Elec_6.3x5.9; Mfg PN APXN100ARA181MF61G
D1, D2, D3: Vr=60V; D_SOD-123F; Mfg PN ATV02W600B-HF
D4, D12, D13: D_Small_ALT; D_SMA; Mfg PN SK220ATR
D5: D_Schottky_Small_ALT; D_SMA; Mfg PN SK220ATR
D6, D7, D8: Green; LED_0603_1608Metric_Pad1.05x0.95mm_HandSolder
D9: Red; LED_0603_1608Metric_Pad1.05x0.95mm_HandSolder
D10: Yellow; LED_0603_1608Metric_Pad1.05x0.95mm_HandSolder
D11: Vr=60V; D_SOD-123F; Mfg PN SMF4L18CA
H1: Enclosure_WM032C; Mfg PN WM032C
H2: Light_Pipe_3x1_7511B11; Mfg PN 7511B11
H3, H4: M3; MountingHole_3mm_Pad_Via_NoPTH
J1, J2: 6P6C; RJ12_Amphenol_54601; Mfg PN 54601-906WPLF
J3: Conn_02x02_Odd_Even; PinSocket_2x02_P2.54mm_Vertical
J4: Conn_01x08; PinSocket_1x08_P2.54mm_Vertical
J5: RJHSE-5081; RJ45_Amphenol_RJHSE508X
L1: 68uH 100mOhm; L_Bourns_SRR1210A; Mfg PN SRR1210-680M
Q1: Si2337DS; SOT-23; Mfg PN SI2337DS-T1-E3
R1, R2, R5: 33k; R_0805_2012Metric
R3: 118k; R_0805_2012Metric
R4, R7, R8, R9: 47k; R_0805_2012Metric
R6: 2x10k; R_0805_2012Metric
R10: 845; R_0805_2012Metric
R11, R12: 680; R_0805_2012Metric
R13: 12k; R_0805_2012Metric
R14: 10m 0.5W; R_1206_3216Metric
R16: 80.6k; R_0805_2012Metric
R17, R21, R22, R25, R26: 10k; R_0805_2012Metric
R18: 3.32k; R_0805_2012Metric
R19, R20, R24: 1k; R_0805_2012Metric
R23: 0-DNP; R_0805_2012Metric
R27, R28: 4.7k-DNP; R_0805_2012Metric
U1: LM5085MY; MSOP-8-1EP_3x3mm_P0.65mm_EP1.88x2mm_ThermalVias0.3mm
U2, U3, U4: TLP185; SOIC-4_4.55x3.7mm_P2.54mm; Mfg PN 140356145100
U5: MAX3485; SOIC-8_3.9x4.9mm_P1.27mm

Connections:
+5V: A1.VUSB (VBUS), C6.1, C7.1, C8.1, C9.1, D6.2 (A), L1.2, R17.1
+BATT: C1.1, C2.1, C3.1, C4.1, D4.1 (K), J5.10, R3.1, R10.1, R14.1, U1.8 (VIN), U2.6, U3.6
/CONN_ADC1: J4.2, R9.1
/CONN_ADC2: J4.4, R8.1
/CONN_ADC3: J4.6, R7.1
/CONN_ADC4: J4.8, R4.1
/MAG_NET_A: J1.5, J2.2, U5.6 (A)
/MAG_NET_B: J1.2, J2.5, U5.7 (B)
/MAG_NET_GND: D11.2 (A2), D12.2 (A), J1.4, J2.3, R21.2
/MAG_NET_GND_K: D9.2 (A), D12.1 (K)
/MAG_NET_GND_R: D8.1 (K), R21.1
/MAG_NET_P14V: D11.1 (A1), D13.2 (A), J1.3, J2.4, R22.2
/MAG_NET_P14V_K: D8.2 (A), D13.1 (K)
/MAG_NET_P14V_R: D9.1 (K), R22.1
/MATE_NET_IND_A: J5.12, R1.2
/MATE_NET_IND_R: R1.1, U2.4
/MATE_NET_RXD: D2.1 (A1), J5.6, U4.1
/MATE_NET_RXD_K: R6.1, U4.3
/MATE_NET_TXD: D1.1 (A1), J5.3, R5.1, U3.4
/P3V3_K: D7.1 (K), R20.1
/P5V_AC: C5.1, C6.2, R16.2
/P5V_ADJ: C4.2, R10.2, U1.1 (ADJ)
/P5V_ISEN: Q1.2 (S), R14.2, U1.5 (ISEN)
/P5V_K: D6.1 (K), R19.1
/P5V_PGATE: Q1.1 (G), U1.6 (PGATE)
/P5V_SW: D5.1 (K), L1.1, Q1.3 (D), R16.1
/P5V_VCC: C3.2, U1.7 (VCC)
/PBATT_CONN: D3.1 (A1), D4.2 (A), J5.1
/PBATT_K: J5.9, R2.1
/PB_ADC1: A1.A1 (18_P0.04_PWM2_ADC1), R9.2
/PB_ADC2: A1.A2 (17_P0.28_PWM2_ADC2), R8.2
/PB_ADC3: A1.A3 (16_P0.29_PWM2_ADC3), R7.2
/PB_ADC4: A1.A4 (15_P0.30_PWM3_ADC4), R4.2
/PB_D2: A1.D2 (SDA1_UART1_RTS_SPI1_SCK_PWM3_P1.01_2), R24.2
/PB_D2_R: D10.1 (K), R24.1
/PB_D3: A1.D3 (SCL1_UART1_CTS_SPI1_MOSI_PWM3_P1.02_3), R23.1
/PB_PWM2: A1.A0 (19_P0.03_PWM2_ADC0), U2.1
/PB_SCL: A1.SCL (1_SCL_P0.27), J3.4, R27.2
/PB_SDA: A1.SDA (0_SDA_P0.26), J3.2, R28.2
/PB_UART1_RX: A1.RX (10_P0.08_UART1_RX), R13.1, U4.4
/PB_UART1_TX: A1.TX (9_P0.06_UART1_TX), U3.1
/PB_UART2_RX: A1.D5 (UART2_RX_PWM1_P1.10_5), R26.2, U5.1 (RO)
/PB_UART2_TX: A1.D4 (UART2_TX_SPI1_MISO_PWM1_P1.08_4), U5.4 (DI)
/U5_EN: R23.2, R25.1, U5.2 (~RE), U5.3 (DE)
GND: A1.GND, C1.2, C2.2, C7.2, C8.2, C9.2, D1.2 (A2), D2.2 (A2), D3.2 (A2), D5.2 (A), J3.3, J4.3, J4.5, J4.7, J5.2, J5.11, R2.2, R5.2, R6.2, R11.2, R12.2, R13.2, R18.2, R19.2, R20.2, R25.2, U1.4 (GND), U1.9 (EP), U5.5 (GND)
unnamed: C5.2, R17.2, R18.1, U1.3 (FB)
unnamed: R3.2, U1.2 (RT)
unnamed: R11.1, U2.3
unnamed: R12.1, U3.3

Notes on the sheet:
Int. Btn.
Green
Int. PU
To Remote
ADC Expansion for DC/AC Current
Int. PU
Green: Mag Net Ok Yellow: Mag Net Traffic Red: Mag Net Flipped
1.1mA @ 14V
MATE Net UART @ Vbatt 9600 9n1
1.1mA @ 56V limiting
drives 0.4+mA match int. 11-16k PD
Blink traffic LED w/ Boron PWM @ 5Hz
VinMin=16.0V VinMax=58.0V Vout=5.0V Iout=1.5A
Note: Not connecting Mag Net GND due to risk of 14V/GND short.
From Inverter
from Boron
MATE Vbatt 24V Sys: 16-28.4Vdc 48V Sys: 32-56.8Vdc
to Boron
tx sinks 3.1mA @(3.3V-1.2Vf) -> 680ohm PD, 6.5mW
I2C Expansion for DC/AC Current
tx drives up to 2.4mA + PD @24V -> 33k PD, 0.017mW rx sinks 4.4mA@(24V-1.1Vf) -> 5k, 0.1mW 0.8mA@4V (for 5V loopback)
1.4mA @ 48V
1.1mA @ 3.3V
UART @ 3.3V 9600 9n1
Yellow

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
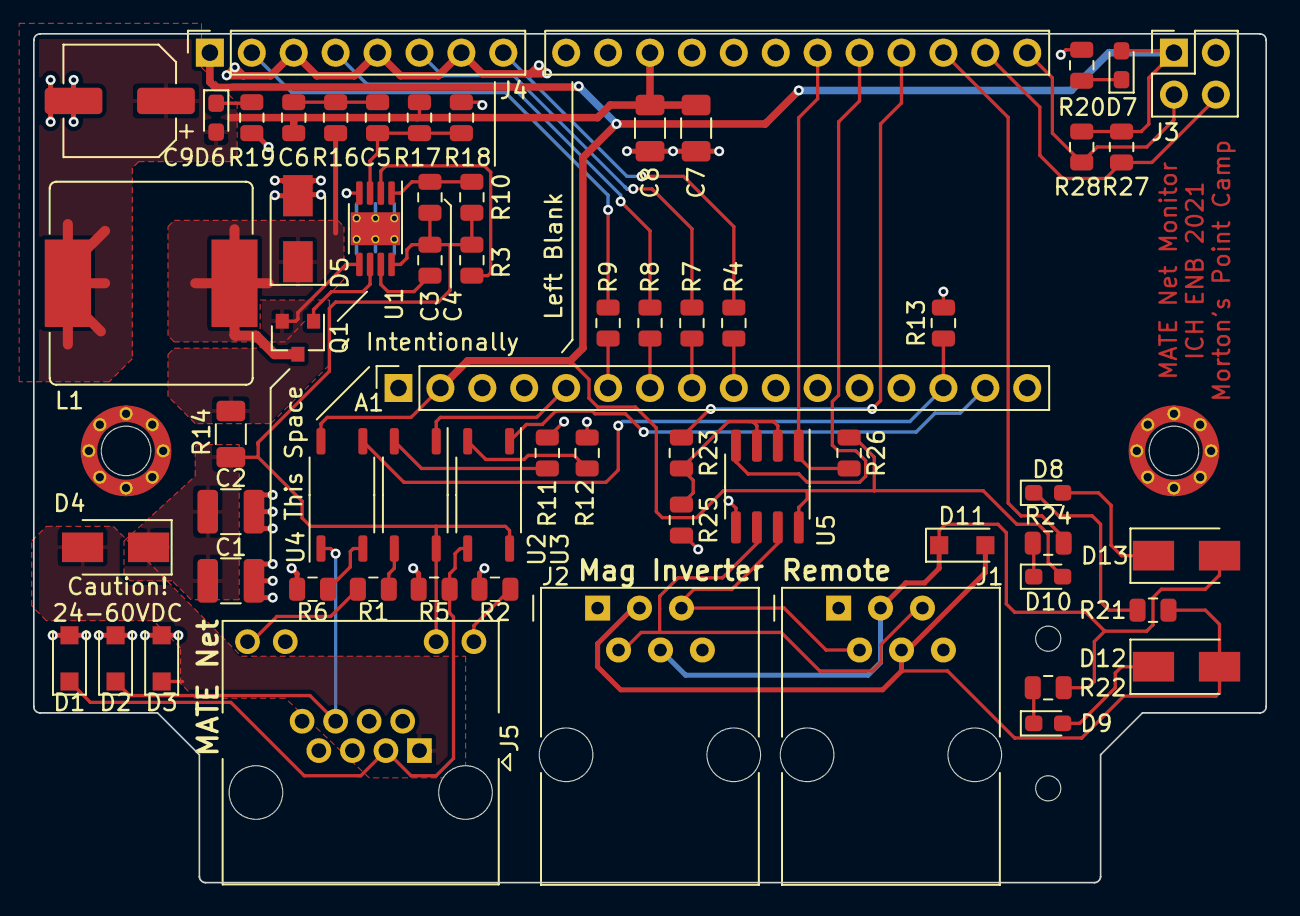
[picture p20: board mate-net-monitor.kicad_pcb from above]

Board: 2 copper layers, 74.7 x 51.4 mm, 66 parts (0 on the bottom side), 50 nets.

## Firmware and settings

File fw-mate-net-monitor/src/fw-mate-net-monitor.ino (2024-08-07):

/*
 * Project fw-mate-net-monitor
 * Description: represents a MATE controller asking for status.
 * Author: Ian Hartwig
 * Date:
 */

#include "MAX3100Serial.h"
#include "uMate.h"

// hw config
// mate net pins
// using a MAX3100 SPI UART instead
const pin_t PIN_MATE_UART_CS = A5;
const pin_t PIN_MATE_UART_IRQ = D6;
const pin_t PIN_MATE_IND = A0;
const unsigned long MATE_UART_BAUD = 9600;
const int MATE_UART_XTAL_FREQ_KHZ = 3686;
// mag net pins - not used same uart
// these pin are connected to TX/RX by rework; don't use
const pin_t PIN_MAG_RX = D5;
const pin_t PIN_MAG_TX = D4;
const pin_t PIN_MAG_IND = D2;
const pin_t PIN_MAG_DE = D3;
const unsigned long MAG_UART_BAUD = 19200;
// expansion pins
const pin_t PIN_EXP_ADC1 = A1;
const pin_t PIN_EXP_ADC2 = A2;
const pin_t PIN_EXP_ADC3 = A3;
const pin_t PIN_EXP_ADC4 = A4;
const pin_t PIN_LED = D7;

// uarts config
SerialLogHandler logHandler;  // default to Serial on debug USB
MAX3100Serial mate_uart = MAX3100Serial(MATE_UART_XTAL_FREQ_KHZ, PIN_MATE_UART_CS, PIN_MATE_UART_IRQ);
MateControllerProtocol mate_bus(mate_uart); // connect mate_bus to this Steam9b supporting port
// MateControllerProtocol mate_bus(mate_uart, &Serial);  // debug to USB Serial

// sw config
SYSTEM_MODE(SEMI_AUTOMATIC);
SYSTEM_THREAD(ENABLED);
// event timers - start with negative values for events sooner to startup
const system_tick_t mate_scan_int_ms = 2000;  // also used for status updates
const system_tick_t cloud_update_int_ms = 90000;  // free tier: ~2 msgs/min
const system_tick_t mag_status_old_ms =  1000;
system_tick_t mate_scan_last_ms = -mate_scan_int_ms;
system_tick_t cloud_update_last_ms = -cloud_update_int_ms;
system_tick_t mag_status_last_ms = -mag_status_old_ms;
// data lengths
#define PUB_BUFFER_LEN   (particle::protocol::MAX_EVENT_DATA_LENGTH)
#define MAX_BUFFER_LEN   (100)
#define MATE_PACKET_LEN  (sizeof(packet_t) + 1)
#define MATE_RESP_LEN    (sizeof(response_t) + 1)
#define MATE_RETRIES     9
#define MATE_MX_PRSNT(x) (x & (0x1<<DeviceType::Mx))  // non-zero when MX is present
#define MAGNET_INV_PACKET_LEN 21
#define MAGNET_INV_START_TIMEOUT_MS 35 // < 100-14-8-10-10-10ms gap for reset
#define MAGNET_BYTE_TIMEOUT_MS 7 // ~10ms gap between msg types
#define MAGNET_NC_TIMEOUT_MS 125
#define MAGNET_INV_MODEL 0x73 // MS4448PAE
// mate device ports numbers from scan - default to -1 not found
int mate_port_hub = -1;
int mate_port_fx = -1;
int mate_port_mx = -1;
int mate_port_flexnetdc = -1;
int mate_port_dc = -1;
int mate_devices_found = 0;  // bit mask of the mate devices found
// mag net Inverter Data
int magnet_ok_cnt; // this might roll over, but we don't care
int magnet_bad_cnt;
int magnet_nc_cnt;
int magnet_dat_cnt;
int magnet_q_cnt;
enum MagNetReturn {
    Ok = 0,
    ShortFrame = -1,
    NotConnected = -2,
    TooLongFrame = -3,
    DataInvalid = -5,
    Unknown = -6,
};
typedef struct MagNetInvMsg {
// Name              Byte   Comments
  uint8_t inv_status;   // 0      See MagInvStatus
  uint8_t inv_fault;    // 1      See MagInvFault
  uint16_t dc_volts;     // 2,3    1 count = 0.1V (real range = 0-100.0V)
  uint16_t dc_amps;      // 4,5    0-500 amps DC
  uint8_t ac_volts_out; // 6      0-150 Volts ac RMS MS Inverter rev 3.0 and later
  uint8_t ac_volts_in;  // 7      0-255 Volts ac peak MS Inverter rev 3.0 and later
  uint8_t inv_led;      // 8      IF = 0, then INV LED is off else INV Led on remote ON
  uint8_t chg_led;      // 9      IF = 0, then CHG LED is off else CHG Led on remote ON*/
  uint8_t inv_rev;      // 10     i.e. 10 = 1.0 Non-zero is mandatory for remote startup
  uint8_t batt_temp;    // 11     0-150 = 0-150 deg C
  uint8_t tran_temp;    // 12     0-150 = 0-150 deg C
  uint8_t fet_temp;     // 13     0-150 = 0-150 deg C*/
  uint8_t inv_model;    // 14     See MagInvModel
  // uint8_t blank;        // 15
  // 21 bit version
  uint8_t stack_mode;   // 15     See MagInvStackMode
  uint8_t ac_amps_in;   // 16     1 count = 1 Amp AC
  uint8_t ac_amps_out;  // 17     1 count = 1 Amp AC
  uint16_t ac_hz;       // 18,19  1 count = 0.1Hz
  uint8_t blank;        // 20
} MagNetInvMsg;
MagNetInvMsg new_inv_msg;
MagNetInvMsg last_inv_msg;
// particle cloud variables
uint8_t mate_status_buf[STATUS_RESP_SIZE+1];  // size from MateNetPort.h
int mate_status_mx_cnt_rx = 0;
int mate_status_mx_cnt_err = 0;
system_tick_t mate_status_last_ms = 0;  // timestamp of the last status update
char mate_monitor_stats[PUB_BUFFER_LEN];
char mate_status_mx_hex[(STATUS_RESP_SIZE*2)+1];  // encode response in hex chars
char mate_status_mx[PUB_BUFFER_LEN];
char mag_status_inv[PUB_BUFFER_LEN];


void setup() {
  // mate net pin setup
  pinMode(PIN_MATE_IND, OUTPUT);
  analogWrite(PIN_MATE_IND, 255, 5);  // 0% 5Hz blink effect
  // analogWrite(PIN_MATE_IND, 127, 5);  // 50% 5Hz blink effect
  // .begin sets up PIN_MATE_UART_CS, PIN_MATE_UART_IRQ, and SPI interface
  mate_uart.begin(MATE_UART_BAUD, 1);  // parity enable for 9-bit mode
  // pinSetDriveStrength does not seem to work with analogWrite and Serial1
  // mag net pin setup
  pinMode(PIN_MAG_RX, INPUT);
  pinMode(PIN_MAG_TX, INPUT);
  pinMode(PIN_MAG_IND, OUTPUT);  // open-drain to vcc
  pinMode(PIN_MAG_DE, INPUT_PULLDOWN);  // listen only
  digitalWrite(PIN_MAG_IND, PinState::LOW);  // on no blink
  // analogWrite(PIN_MAG_IND, 127, 5);  // 50% 5Hz blink effect
  Serial1.begin(MAG_UART_BAUD, SERIAL_8N1);
  // mate_bus.set_timeout(200);  // per-msg; default timeout 100ms
  // expansion pins setup
  pinMode(PIN_EXP_ADC1, INPUT);
  pinMode(PIN_EXP_ADC2, INPUT);
  pinMode(PIN_EXP_ADC3, INPUT);
  pinMode(PIN_EXP_ADC4, INPUT);
  // debug logging to usb serial
  delay(2000);  // console reconnect
  // auto logManager = LogManager::instance();
  // auto logTraceHandler = new StreamLogHandler(Serial, LOG_LEVEL_TRACE);
  // logManager->addHandler(logTraceHandler);
  spark::Log.trace(String::format("%s: %s", Time.timeStr().c_str(), "MATE emulator: Hello world!"));
  // particle cloud
  Particle.connect();
  spark::Log.info("MATE emulator: particle cloud ready");
  // digitalWrite(D7, PinState::LOW);
}


// sets a bit-mask of the devices found on bus
// returns retries used until scan success or MATE_RETRIES is exceeded
// retries until any other device on the bus is found or -1
int mate_bus_scan() {
  int retries_used = -1;
  mate_devices_found = 0;  // bit mask of the mate devices found
  spark::Log.trace("mate_bus_scan(): looking for mate devices");
  while ((!mate_devices_found) && ++retries_used < MATE_RETRIES) {
    int available_bytes = mate_uart.availableBytes();
    if (available_bytes) {
      spark::Log.trace("mate_bus_scan(): purging read buf");
    }
    mate_uart.readBufPurge();
    mate_bus.scan_ports();
    // mate device ports from scan with -1 not found
    mate_port_hub = mate_bus.find_device(DeviceType::Hub);
    mate_port_fx = mate_bus.find_device(DeviceType::Fx);
    mate_port_mx = mate_bus.find_device(DeviceType::Mx);
    mate_port_flexnetdc = mate_bus.find_device(DeviceType::FlexNetDc);
    mate_port_dc = mate_bus.find_device(DeviceType::Dc);
    // diag for device presence
    mate_devices_found = 0;
    mate_devices_found |= (1 & (mate_port_hub!=-1))<<DeviceType::Hub;
    mate_devices_found |= (1 & (mate_port_fx!=-1))<<DeviceType::Fx;
    mate_devices_found |= (1 & (mate_port_mx!=-1))<<DeviceType::Mx;
    mate_devices_found |= (1 & (mate_port_flexnetdc!=-1))<<DeviceType::FlexNetDc;
    mate_devices_found |= (1 & (mate_port_dc!=-1))<<DeviceType::Dc;
  }
  spark::Log.trace("mate_bus_scan(): exiting with devices 0x%x after %d retries", mate_devices_found, retries_used);
  return retries_used;
}


// unpack the 13 byte (STATUS_RESP_SIZE) MX status response
// reverse engineering from
// https://github.com/jorticus/pymate/blob/master/pymate/matenet/mx.py
void mate_mx_status_unpack(uint8_t *mate_status_buf, char *mx_status_buf, system_tick_t update_ms) {
  uint8_t *values = mate_status_buf;
  float bat_current_milli = (float)(values[0] & 0x0F) / 10.0;
  snprintf(
    mx_status_buf,
    PUB_BUFFER_LEN,
    "{"
      "\"uptime_ms\": %ld, "
      "\"mx_today_ah\": \"%d\", "
      "\"mx_today_kwh\": %.1f, "
      "\"mx_bat_cur_a\": %.1f, "
      "\"mx_pv_cur_a\": %.1f, "
      "\"mx_aux_mode_state\": \"0x%x\", "
      "\"mx_status\": \"0x%x\", "
      "\"mx_errors\": \"0x%x\", "
      "\"mx_bat_v\": %.1f, "
      "\"mx_pv_v\": %.1f"
    "}",
    update_ms,
    // The following was determined by poking values at the MATE unit...
    ((values[0] & 0x70) >> 4) | values[4],  // bat Ah - ignore bit7 (if 0, MATE hides the AH reading)
    (float)((values[3] << 8) | values[8]) / 10.0, //  kWh
    (float)((128 + (int8_t)values[2]) % 256) + bat_current_milli,  // bat current A
    (float)((128 + (int8_t)values[1]) % 256),  // pv current A
    values[5],  // aux mode (& 0x3F) state (& 0x40 == 0x40)
    values[6],  // status bitfield
    values[7],  // error bitfield
    (float)SWAPENDIAN_16(*(uint16_t *)(&values[9])) / 10.0,  // bat v in V
    (float)SWAPENDIAN_16(*(uint16_t *)(&values[11])) / 10.0  // pv v in V
  );
}


// gathers a new MX Charger status and transcribes that to ascii-hex
// when one is on a known port set by mate_port_mx.
// returns retries used until new status or MATE_RETRIES is exceeded or -1
int mate_mx_status () {
  int retries_used = -1;
  bool new_status = false;
  spark::Log.trace("mate_mx_status(): looking for MX Charger status");
  while (mate_port_mx != -1 && !new_status && ++retries_used < MATE_RETRIES) {
    int available_bytes = mate_uart.availableBytes();
    if (available_bytes) {
      spark::Log.trace("mate_mx_status(): purging read buf");
    }
    mate_uart.readBufPurge();
    new_status = mate_bus.read_status(mate_status_buf, STATUS_RESP_SIZE, 1, mate_port_mx);
    // todo: maybe we should timeout for this. apparently there is?
    if (new_status) {
      mate_status_mx_cnt_rx++;
      mate_status_last_ms = millis();
    } else {
      mate_status_mx_cnt_err++;
    }
  }
  // convert to hex string byte of status response at a time
  if (!new_status) {
    // blank out mate_status_buf if there was no new status
    memset((char *)&mate_status_buf, 0, STATUS_RESP_SIZE);
  }
  for (int i = 0; i < STATUS_RESP_SIZE; i++) {
    snprintf(((char *)(&mate_status_mx_hex[i*2])), 3, "%02x", mate_status_buf[i]);
  }  // null terminator added by last snprintf
  // convert status response to json 
  mate_mx_status_unpack(mate_status_buf, mate_status_mx, mate_status_last_ms);
  spark::Log.trace("mate_mx_status(): exiting after %d retries", retries_used);
  return retries_used;
}


/*
 * Find and read an inverter message from Serial1 to buf. Waits for
 * MAGNET_INV_START_TIMEOUT_MS but not more than MAGNET_NC_TIMEOUT_MS so as to
 * not block the main loop.
 *
 * Returns: 0 on complete message, -1 incomplete buffer, -2 nc timeout
 */
int magnet_read_inv_msg(char* buf, int buf_len) {
  int buf_i = 0;
  int new_byte = 0;
  bool inv_sync = false;
  volatile unsigned long new_byte_time = 0;
  volatile unsigned long last_byte_time = millis();
  while(true) {
    // read byte
    if(Serial1.available()) {
      new_byte = Serial1.read();
    }
    else {
      new_byte = -1;
    }
    // handle new byte
    new_byte_time = millis();
    if(new_byte >= 0) {
      // wait for long gap before inverter talks
      if(new_byte_time > last_byte_time + MAGNET_INV_START_TIMEOUT_MS) {
        inv_sync = true;
        // also need to reset the byte time since we may have been looking a while
        last_byte_time = new_byte_time;
      }
      // and just keep spinning if we haven't found it
      if(!inv_sync) {
        continue;
      }
      // too much time between bytes means another dev is talking now; abort
      else if (new_byte_time > last_byte_time + MAGNET_BYTE_TIMEOUT_MS) {
        return MagNetReturn::ShortFrame; // dropped packet
      }
      // record the new byte
      buf[buf_i] = new_byte;
      buf_i++;
      last_byte_time = new_byte_time;
      // check if we have a complete packet
      if(buf_i == MAGNET_INV_PACKET_LEN) {
        return MagNetReturn::Ok; // filled packet
      }
      else if (buf_i >= MAGNET_INV_PACKET_LEN) {
        return MagNetReturn::TooLongFrame; // oops! stop the overflow
      }
      // else keep looking for bytes
    }
    // let the loop move forward if we're not finding anything
    else if (new_byte_time > last_byte_time + MAGNET_NC_TIMEOUT_MS) {
      return MagNetReturn::NotConnected;
    }
    // else: keep trying to read
    // break;
  } // end while
  return MagNetReturn::Unknown;
}


int magnet_interp_inv_msg(char* buf, char* inv_status, int buf_len) {
  MagNetInvMsg inv_msg;
  // fix endianness for 2-byte fields
  uint8_t swap;
  swap = buf[2];
  buf[2] = buf[3];
  buf[3] = swap;
  swap = buf[4];
  buf[4] = buf[5];
  buf[5] = swap;
  swap = buf[18];
  buf[18] = buf[19];
  buf[19] = swap;
  // shove the inverter packet into struct
  memcpy(&inv_msg, buf, sizeof(inv_msg));

  // sanity check this packet data
  if(inv_msg.inv_model != MAGNET_INV_MODEL) {
    return MagNetReturn::DataInvalid;
  }

  // convert to json string format
  snprintf(
    inv_status,
    PUB_BUFFER_LEN,
    "{"
      "\"inv_status\": %d, "
      "\"dc_volts\": %d, "
      "\"dc_amps\": %d, "
      "\"ac_volts_out\": %d, "
      "\"ac_volts_in\": %d, "
      "\"batt_temp\": %d, "
      "\"tran_temp\": %d, "
      "\"fet_temp\": %d, "
      "\"ac_amps_in\": %d, "
      "\"ac_amps_out\": %d, "
      "\"ac_hz\": %d"
    "}",
    inv_msg.inv_status,
    inv_msg.dc_volts,
    inv_msg.dc_amps,
    inv_msg.ac_volts_out,
    inv_msg.ac_volts_in,
    inv_msg.batt_temp,
    inv_msg.tran_temp,
    inv_msg.fet_temp,
    inv_msg.ac_amps_in,
    inv_msg.ac_amps_out,
    inv_msg.ac_hz);
  return 0;
}


void loop() {
  // first check for mag device updates since these stream in all the time
  char mag_inv_packet[MAGNET_INV_PACKET_LEN];
  memset(mag_inv_packet, 0, MAGNET_INV_PACKET_LEN);
  int magnet_ret = -6;
  magnet_ret = magnet_read_inv_msg(mag_inv_packet, MAGNET_INV_PACKET_LEN);
  if (magnet_ret == 0) {
    magnet_ret = magnet_interp_inv_msg(mag_inv_packet, mag_status_inv, MAGNET_INV_PACKET_LEN);
    mag_status_last_ms = millis();
    analogWrite(PIN_MAG_IND, 127, 5);  // 50% 5Hz blink effect
    magnet_ok_cnt++;
  }
  else {
    digitalWrite(PIN_MAG_IND, PinState::LOW);  // on no blink
    switch (magnet_ret) {
    case MagNetReturn::ShortFrame:  // dropped packet
      magnet_bad_cnt++;
      break;
    case MagNetReturn::NotConnected:  // not connected timeout
      magnet_nc_cnt++;
      break;
    case MagNetReturn::DataInvalid:  // data invalid - wrong inverter model
      magnet_dat_cnt++;
      break;
    default: // we don't know what's happening anymore
      magnet_q_cnt++;
      break;
    }
  }
  // then request mate updates on action interval
  int mate_scan_retries = 0;
  int mate_status_retries = 0;
  // skip the rest if we haven't reach an action interval yet
  system_tick_t now_ms = millis();
  if (now_ms - mate_scan_last_ms < mate_scan_int_ms) {
    return;
  }
  mate_scan_last_ms = now_ms;
  // look for devices - this is mostly diagnostic
  // sets mate_devices_found and mate_port_mx
  mate_scan_retries = mate_bus_scan();
  if (mate_devices_found) {
    analogWrite(PIN_MATE_IND, 127, 5); // 50% 5Hz blink effect
  } else {
    digitalWrite(PIN_MATE_IND, PinState::HIGH);  // on no blink
  }
  // continue to get MX Charger status if we see one is connected
  // uses mate_port_mx and sets mate_scan_retries, mate_status_last_ms, etc
  mate_status_retries = mate_mx_status();
  // publish MX Charger status - with or without response
  // approx strlen 236~300 chars
  snprintf(
    mate_monitor_stats,
    PUB_BUFFER_LEN,
    "{"
      "\"uptime_ms\": %ld, "
      "\"mate_devices_found\": \"0x%x\", "
      "\"mate_scan_retries\": %d, "
      "\"mate_status_mx_cnt_rx\": %d, "
      "\"mate_status_mx_cnt_err\": %d, "
      "\"mate_status_mx\": \"0x%s\", "
      "\"mate_status_retries\": %d, "
      "\"mate_status_last_ms\": %ld, "
      "\"magnet_ok_cnt\": %d, "
      "\"magnet_bad_cnt:\" %d, "
      "\"magnet_nc_cnt:\" %d "
      "\"magnet_dat_cnt:\" %d, "
      "\"magnet_q_cnt:\" %d"
    "}",
    millis(),
    mate_devices_found, mate_scan_retries,
    mate_status_mx_cnt_rx, mate_status_mx_cnt_err,
    mate_status_mx_hex, mate_status_retries,
    mate_status_last_ms,
    magnet_ok_cnt, magnet_bad_cnt, magnet_nc_cnt, magnet_dat_cnt, magnet_q_cnt
  );
  spark::Log.info("mate_monitor_stats (len %d):", strlen(mate_monitor_stats));
  spark::Log.print(mate_monitor_stats);  // to print over 200 chars
  spark::Log.print("\n");
  spark::Log.info("mate_status_mx (len %d):", strlen(mate_status_mx));
  spark::Log.print(mate_status_mx);  // to print over 200 chars
  spark::Log.print("\n");
  spark::Log.info("mag_status_inv (len %d):", strlen(mag_status_inv));
  spark::Log.print(mag_status_inv);  // to print over 200 chars
  spark::Log.print("\n");
  spark::Log.info(String::format("now_ms-cloud_update_last_ms: %ld, cloud_update_int_ms: %ld", now_ms-cloud_update_last_ms, cloud_update_int_ms));
  // cloud update at a slower rate
  if (now_ms - cloud_update_last_ms >= cloud_update_int_ms && Particle.connected()) {
    auto pub_ret = Particle.publish("fw-mate-net-monitor-status", mate_monitor_stats);
    spark::Log.info("Particle.publish(\"fw-mate-net-monitor-status\", ...): %d", !!pub_ret);
    // publish mate status if we got a successful update
    if (mate_status_retries >= 0) {
      auto pub_ret = Particle.publish("mate-status-mx", mate_status_mx);
      spark::Log.info("Particle.publish(\"mate-status-mx\", ...): %d", !!pub_ret);
    }
    // publish mag status if we got an update within timeout
    if (now_ms - mag_status_last_ms < mag_status_old_ms) {
      auto pub_ret = Particle.publish("mag-status-inv", mag_status_inv);
      spark::Log.info("Particle.publish(\"mag-status-inv\", ...): %d", !!pub_ret);
    }
    cloud_update_last_ms = now_ms;
  }
  return;
}

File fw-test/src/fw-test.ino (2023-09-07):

/*
 * Project fw-test
 * Description: Boron + Mate Net interface test firmware.
 * Author: Ian Hartwig
 * Date: 30 Jul 2022
 */

#include "MAX3100Serial.h"
#include "PacketSerial.h"

#include <SPI.h>

// hw config
// mate net pins
// using a MAX3100 SPI UART instead
const pin_t PIN_MATE_UART_CS = A5;
const pin_t PIN_MATE_UART_IRQ = D6;
const pin_t PIN_MATE_IND = A0;
const unsigned long MATE_UART_BAUD = 9600;
const int MATE_UART_XTAL_FREQ_KHZ = 3686;
// mag net pins - not used same uart
// these pin are connected to TX/RX by rework; don't use
const pin_t PIN_MAG_RX = D5;
const pin_t PIN_MAG_TX = D4;
const pin_t PIN_MAG_IND = D2;
const pin_t PIN_MAG_DE = D3;
const unsigned long MAG_UART_BAUD = 9600;
// expansion pins
const pin_t PIN_EXP_ADC1 = A1;
const pin_t PIN_EXP_ADC2 = A2;
const pin_t PIN_EXP_ADC3 = A3;
const pin_t PIN_EXP_ADC4 = A4;
const pin_t PIN_LED = D7;

// uarts config
SerialLogHandler logHandler;  // default to Serial on debug USB
MAX3100Serial mate_uart = MAX3100Serial(MATE_UART_XTAL_FREQ_KHZ, PIN_MATE_UART_CS, PIN_MATE_UART_IRQ);

// sw config
SYSTEM_MODE(SEMI_AUTOMATIC);

// test serial buffer config
typedef PacketSerial_<COBS, 0, 256> PacketSerial;
PacketSerial mate_net_packet_serial;
PacketSerial mag_net_packet_serial;
// const int packet_buf_len = 1500 * 3;  // borrow from ethernet + overhead
const int packet_buf_len = 256;
// test packet from prbs_generate.js prbs11
// char test_packet_buf[] = \
//   "\x80\x50\x22\x15\x48\x0d\x07\x23\x75\xd4\x50\xa2\x45\x6a\x18\x4f\x2e\x72\xf7\x25\x76\x15\xc8\x5d\x25\x36\x3d\xd9\x57\x81\x30\xbe\x48\xed\x6b\x18\xef\x6a\x58\x67\x3f\x78\x53\x23\xf5\x84\x72\xb7\x0d\x67\x1f\x6c\x5b\xa6\xa7\x87\x33\x7f\xd0\x12\x0b\x44\xca\xfc\x21\x94\xf8\xe3\x6d\xdb\x56\xc1\xb8\xeb\x68\xd9\x77\x95\x38\x3b\x1a\xee\x2a\xd0\x32\x1f\x4c\x4f\xae\x22\xd5\x30\x3e\x18\xcf\x7e\x50\xe2\x6d\x7b\x12\xeb\x28\xf1\x66\x9f\x9c\x3d\x99\x7f\x90\x3a\x1a\x4e\x6e\xfa\xa2\x05\x42\x09\x45\x8a\x74\x74\xb4\xcc\xff\xe0\x0c\x07\x83\x31\xfe\xc0\xb8\x4b\x2c\xf3\xe7\x8f\x36\x7d\xf1\x46\x8b\x94\xb8\xcb\x7c\xd1\xf2\xc7\x3b\x7a\xd2\x33\x5f\xc4\x1a\x8e\x16\xc9\xbd\xe9\x49\x8d\xf7\x45\x4a\x0c\x47\xab\x20\xf4\x64\xbe\xc8\xbd\x49\x0d\xa7\x67\x5f\x44\x4a\xac\x03\x81\xb0\xee\x6a\xf8\x23\x15\xe8\x49\x2d\xb3\x6f\xda\x16\x49\xed\xcb\x5c\xc5\xfa\x42\x69\x79\x93\xfb\x82\xb1\x0e\xa6\x87\x93\x3b\xfa\x82\x11\x4a\x8c\x17\x89\x35\xbc\x69\xb9\xeb\xc8\x9d\x5d\x05\x22\x35\x5c\x05\x82\x71\x76\x95\x98\x7f\x30\x7e\x30\xde\x74\xf4\xe4\xee\xea\xa8\x00"\
//   "\x80\x50\x22\x15\x48\x0d\x07\x23\x75\xd4\x50\xa2\x45\x6a\x18\x4f\x2e\x72\xf7\x25\x76\x15\xc8\x5d\x25\x36\x3d\xd9\x57\x81\x30\xbe\x48\xed\x6b\x18\xef\x6a\x58\x67\x3f\x78\x53\x23\xf5\x84\x72\xb7\x0d\x67\x1f\x6c\x5b\xa6\xa7\x87\x33\x7f\xd0\x12\x0b\x44\xca\xfc\x21\x94\xf8\xe3\x6d\xdb\x56\xc1\xb8\xeb\x68\xd9\x77\x95\x38\x3b\x1a\xee\x2a\xd0\x32\x1f\x4c\x4f\xae\x22\xd5\x30\x3e\x18\xcf\x7e\x50\xe2\x6d\x7b\x12\xeb\x28\xf1\x66\x9f\x9c\x3d\x99\x7f\x90\x3a\x1a\x4e\x6e\xfa\xa2\x05\x42\x09\x45\x8a\x74\x74\xb4\xcc\xff\xe0\x0c\x07\x83\x31\xfe\xc0\xb8\x4b\x2c\xf3\xe7\x8f\x36\x7d\xf1\x46\x8b\x94\xb8\xcb\x7c\xd1\xf2\xc7\x3b\x7a\xd2\x33\x5f\xc4\x1a\x8e\x16\xc9\xbd\xe9\x49\x8d\xf7\x45\x4a\x0c\x47\xab\x20\xf4\x64\xbe\xc8\xbd\x49\x0d\xa7\x67\x5f\x44\x4a\xac\x03\x81\xb0\xee\x6a\xf8\x23\x15\xe8\x49\x2d\xb3\x6f\xda\x16\x49\xed\xcb\x5c\xc5\xfa\x42\x69\x79\x93\xfb\x82\xb1\x0e\xa6\x87\x93\x3b\xfa\x82\x11\x4a\x8c\x17\x89\x35\xbc\x69\xb9\xeb\xc8\x9d\x5d\x05\x22\x35\x5c\x05\x82\x71\x76\x95\x98\x7f\x30\x7e\x30\xde\x74\xf4\xe4\xee\xea\xa8\x00"\
//   "\x80\x50\x22\x15\x48\x0d\x07\x23\x75\xd4\x50\xa2\x45\x6a\x18\x4f\x2e\x72\xf7\x25\x76\x15\xc8\x5d\x25\x36\x3d\xd9\x57\x81\x30\xbe\x48\xed\x6b\x18\xef\x6a\x58\x67\x3f\x78\x53\x23\xf5\x84\x72\xb7\x0d\x67\x1f\x6c\x5b\xa6\xa7\x87\x33\x7f\xd0\x12\x0b\x44\xca\xfc\x21\x94\xf8\xe3\x6d\xdb\x56\xc1\xb8\xeb\x68\xd9\x77\x95\x38\x3b\x1a\xee\x2a\xd0\x32\x1f\x4c\x4f\xae\x22\xd5\x30\x3e\x18\xcf\x7e\x50\xe2\x6d\x7b\x12\xeb\x28\xf1\x66\x9f\x9c\x3d\x99\x7f\x90\x3a\x1a\x4e\x6e\xfa\xa2\x05\x42\x09\x45\x8a\x74\x74\xb4\xcc\xff\xe0\x0c\x07\x83\x31\xfe\xc0\xb8\x4b\x2c\xf3\xe7\x8f\x36\x7d\xf1\x46\x8b\x94\xb8\xcb\x7c\xd1\xf2\xc7\x3b\x7a\xd2\x33\x5f\xc4\x1a\x8e\x16\xc9\xbd\xe9\x49\x8d\xf7\x45\x4a\x0c\x47\xab\x20\xf4\x64\xbe\xc8\xbd\x49\x0d\xa7\x67\x5f\x44\x4a\xac\x03\x81\xb0\xee\x6a\xf8\x23\x15\xe8\x49\x2d\xb3\x6f\xda\x16\x49\xed\xcb\x5c\xc5\xfa\x42\x69\x79\x93\xfb\x82\xb1\x0e\xa6\x87\x93\x3b\xfa\x82\x11\x4a\x8c\x17\x89\x35\xbc\x69\xb9\xeb\xc8\x9d\x5d\x05\x22\x35\x5c\x05\x82\x71\x76\x95\x98\x7f\x30\x7e\x30\xde\x74\xf4\xe4\xee\xea\xa8\x00"\
//   "\x80\x50\x22\x15\x48\x0d\x07\x23\x75\xd4\x50\xa2\x45\x6a\x18\x4f\x2e\x72\xf7\x25\x76\x15\xc8\x5d\x25\x36\x3d\xd9\x57\x81\x30\xbe\x48\xed\x6b\x18\xef\x6a\x58\x67\x3f\x78\x53\x23\xf5\x84\x72\xb7\x0d\x67\x1f\x6c\x5b\xa6\xa7\x87\x33\x7f\xd0\x12\x0b\x44\xca\xfc\x21\x94\xf8\xe3\x6d\xdb\x56\xc1\xb8\xeb\x68\xd9\x77\x95\x38\x3b\x1a\xee\x2a\xd0\x32\x1f\x4c\x4f\xae\x22\xd5\x30\x3e\x18\xcf\x7e\x50\xe2\x6d\x7b\x12\xeb\x28\xf1\x66\x9f\x9c\x3d\x99\x7f\x90\x3a\x1a\x4e\x6e\xfa\xa2\x05\x42\x09\x45\x8a\x74\x74\xb4\xcc\xff\xe0\x0c\x07\x83\x31\xfe\xc0\xb8\x4b\x2c\xf3\xe7\x8f\x36\x7d\xf1\x46\x8b\x94\xb8\xcb\x7c\xd1\xf2\xc7\x3b\x7a\xd2\x33\x5f\xc4\x1a\x8e\x16\xc9\xbd\xe9\x49\x8d\xf7\x45\x4a\x0c\x47\xab\x20\xf4\x64\xbe\xc8\xbd\x49\x0d\xa7\x67\x5f\x44\x4a\xac\x03\x81\xb0\xee\x6a\xf8\x23\x15\xe8\x49\x2d\xb3\x6f\xda\x16\x49\xed\xcb\x5c\xc5\xfa\x42\x69\x79\x93\xfb\x82\xb1\x0e\xa6\x87\x93\x3b\xfa\x82\x11\x4a\x8c\x17\x89\x35\xbc\x69\xb9\xeb\xc8\x9d\x5d\x05\x22\x35\x5c\x05\x82\x71\x76\x95\x98\x7f\x30\x7e\x30\xde\x74\xf4\xe4\xee\xea\xa8\x00"\
//   "\x80\x50\x22\x15\x48\x0d\x07\x23\x75\xd4\x50\xa2\x45\x6a\x18\x4f\x2e\x72\xf7\x25\x76\x15\xc8\x5d\x25\x36\x3d\xd9\x57\x81\x30\xbe\x48\xed\x6b\x18\xef\x6a\x58\x67\x3f\x78\x53\x23\xf5\x84\x72\xb7\x0d\x67\x1f\x6c\x5b\xa6\xa7\x87\x33\x7f\xd0\x12\x0b\x44\xca\xfc\x21\x94\xf8\xe3\x6d\xdb\x56\xc1\xb8\xeb\x68\xd9\x77\x95\x38\x3b\x1a\xee\x2a\xd0\x32\x1f\x4c\x4f\xae\x22\xd5\x30\x3e\x18\xcf\x7e\x50\xe2\x6d\x7b\x12\xeb\x28\xf1\x66\x9f\x9c\x3d\x99\x7f\x90\x3a\x1a\x4e\x6e\xfa\xa2\x05\x42\x09\x45\x8a\x74\x74\xb4\xcc\xff\xe0\x0c\x07\x83\x31\xfe\xc0\xb8\x4b\x2c\xf3\xe7\x8f\x36\x7d\xf1\x46\x8b\x94\xb8\xcb\x7c\xd1\xf2\xc7\x3b\x7a\xd2\x33\x5f\xc4\x1a\x8e\x16\xc9\xbd\xe9\x49\x8d\xf7\x45\x4a\x0c\x47\xab\x20\xf4\x64\xbe\xc8\xbd\x49\x0d\xa7\x67\x5f\x44\x4a\xac\x03\x81\xb0\xee\x6a\xf8\x23\x15\xe8\x49\x2d\xb3\x6f\xda\x16\x49\xed\xcb\x5c\xc5\xfa\x42\x69\x79\x93\xfb\x82\xb1\x0e\xa6\x87\x93\x3b\xfa\x82\x11\x4a\x8c\x17\x89\x35\xbc\x69\xb9\xeb\xc8\x9d\x5d\x05\x22\x35\x5c\x05\x82\x71\x76\x95\x98\x7f\x30\x7e\x30\xde\x74\xf4\xe4\xee\xea\xa8\x00";
// const int test_packet_len = (256*5)+1;
// test packet from prbs_generate.js prbs7
char test_packet_buf[] = \
  "\x83\x0a\x3c\x8b\x3a\x9f\x43\x89\x36\xb7\xb1\xa5\xdc\xca\xbf\x80"\
  "\x83\x0a\x3c\x8b\x3a\x9f\x43\x89\x36\xb7\xb1\xa5\xdc\xca\xbf\x80"\
  "\x83\x0a\x3c\x8b\x3a\x9f\x43\x89\x36\xb7\xb1\xa5\xdc\xca\xbf\x80"\
  "\x83\x0a\x3c\x8b\x3a\x9f\x43\x89\x36\xb7\xb1\xa5\xdc\xca\xbf\x80";
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

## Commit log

2021-08-21 new kicad pcba project; boron symbol from darkernoise/kicad
    [mate-net-monitor.kicad_pcb, mate-net-monitor.sch]
2021-08-23 schematic P1 Draft 1
    [mate-net-monitor.sch]
2021-08-23 schematic P1 Draft 2 and footprints
    [mate-net-monitor.sch]
2021-08-23 layout P1 in progress
    [mate-net-monitor.kicad_pcb]
2021-08-24 layout P1
    [mate-net-monitor-B_Cu.gbr, mate-net-monitor-B_Mask.gbr, mate-net-monitor-B_Paste.gbr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]
2021-08-24 schematic P1 Draft 3
2021-08-25 layout P1 schematic P1
    review and fix circuits before fab
    * fix Q1 D/S orientation
    * fix J1/J2 labels to match pin usage
    * add 3d models RJ45, RJ12, Boron, inductor
    * new gerbers and pdfs
    [L_Bourns_SRR1210.stp, RJ12_Amphenol_54601.stp, RJ45_Amphenol_RJHSE508X.step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]
2021-08-25 layout P1.1 update U1 footprint to have 0.3mm vias
    [mate-net-monitor-B_Cu.gbr, mate-net-monitor-B_Mask.gbr, mate-net-monitor-B_Paste.gbr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]
2022-08-03 add fw-test and resistor tweaks to sch
    [mate-net-monitor.kicad_sch]
2022-08-14 add pcb-max3100-uart-adpt pcb
    [SOP64P602X175-16N.stp, max3100-uart-adpt.kicad_pcb, max3100-uart-adpt.kicad_sch]
2022-08-14 add pcb-max3100-uart-adpt gerbers
    [MAX3100EEE+.stp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]
2022-09-03 revert the circular buffer for test
    [fw-test.ino]
2023-07-28 update readme and deviceOS
2023-07-31 add read and write irq with buffer to MAX3100 driver
2023-08-03 sch notes and cleanup
    [mate-net-monitor.kicad_sch]
2023-08-04 fix max3100 concurrency bugs and naming
    [fw-test.ino]
2023-08-27 implement fw-test particle publish and max3100 unplug fix
    [fw-test.ino]
2023-08-28 mag net test rework and fw
    [mate-net-monitor.kicad_sch]
2023-08-29 fix fw-test mag ind blink
    [fw-test.ino]
2023-09-07 fix fault and enable partiy bit in max3100
    [fw-test.ino]
2023-09-10 fw-mate-net-monitor fast led and slow publish loop and README
2023-09-10 attempt to fix mate_bus_scan hang with timeout
    [fw-mate-net-monitor.ino]
2023-09-10 fix retries to infinity
    [fw-mate-net-monitor.ino]
2023-09-10 fix app logic to always request and report mx status
    [fw-mate-net-monitor.ino]
2023-09-10 fix app status json pretty print
    [fw-mate-net-monitor.ino]
2024-08-02 update device os and config, remove swapendian
    [fw-mate-net-monitor.ino]
2024-08-04 fix fw-mate-net-mx-emulator background printing
    [fw-mate-net-mx-emulator.ino]
2024-08-05 fix max3100 isr and fw-mate-net-mx-emulator not reading often enough
    [fw-mate-net-mx-emulator.ino]
2024-08-05 add buffer purge and rework app timers
    [fw-mate-net-monitor.ino]
2024-08-05 misc fixes timers leds disconnects
    [fw-mate-net-monitor.ino]
2024-08-06 add magnet handling to fw-mate-net-monitor
2024-08-07 fix cloud publish timer and magnet counters
    [fw-mate-net-monitor.ino]

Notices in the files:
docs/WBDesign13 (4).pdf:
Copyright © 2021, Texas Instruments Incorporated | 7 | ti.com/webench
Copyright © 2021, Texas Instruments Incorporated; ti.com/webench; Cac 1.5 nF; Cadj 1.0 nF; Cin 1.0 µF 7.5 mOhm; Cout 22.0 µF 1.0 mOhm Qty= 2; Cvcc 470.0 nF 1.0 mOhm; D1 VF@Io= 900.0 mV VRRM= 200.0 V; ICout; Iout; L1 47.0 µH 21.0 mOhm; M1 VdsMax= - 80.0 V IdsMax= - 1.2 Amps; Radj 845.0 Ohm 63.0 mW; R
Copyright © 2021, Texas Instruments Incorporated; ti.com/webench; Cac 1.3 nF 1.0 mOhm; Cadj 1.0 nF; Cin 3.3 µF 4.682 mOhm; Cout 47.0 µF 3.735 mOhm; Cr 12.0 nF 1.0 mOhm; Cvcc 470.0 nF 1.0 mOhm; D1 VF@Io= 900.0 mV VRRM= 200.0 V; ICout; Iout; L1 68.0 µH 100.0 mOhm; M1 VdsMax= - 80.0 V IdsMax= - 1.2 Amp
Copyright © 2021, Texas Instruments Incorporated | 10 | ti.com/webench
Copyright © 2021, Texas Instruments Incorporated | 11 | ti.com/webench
